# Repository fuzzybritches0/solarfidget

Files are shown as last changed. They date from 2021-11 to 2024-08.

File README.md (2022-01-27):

# 		ORIGINAL SOLARFIDGET LIPO EDITION

Using an LED strip (of 32 WS2812B individually addressable LEDs) and an
MPU6050 gyro/accel, this fidget calculates the position of a rotating
pendulum that reacts to acceleration and gravity and simulates the effect
of gravity on different bodies in our solar system (including Pluto).

Concept, Design and Idea **Copyright (C)** 2021, 2022 Kurt Manucredo, under
the CREATIVE COMMONS ATTRIBUTION-NONCOMMERCIAL 4.0 INTERNATIONAL PUBLIC
LICENSE

For more information on Copyright please refer to the respective files and
LICENSE files.

solarfidget
* * *

There is also a version that runs with 3x AAA batteries. Click on the link
below to follow the instructions for the:

**ORIGINAL SOLARFIDGET - NO BATTERIES INCLUDED EDITION**
<https://github.com/fuzzybritches0/solarfidget/blob/main/README-aaa.md>
* * *

# 1. MANUAL INSTRUCTIONS

## 1.1 TRAVEL FROM PLANET TO PLANET

You can travel the following bodies in our solarsystem in order:

- Mercury (0.38g)   (white)
- Venus   (0.904g)  (light blue)
- Earth   (1g)      (dark blue)
- Mars    (0.3794g) (red brown)
- Jupiter (2.528g)  (white grey)
- Saturn  (1.065g)  (yellow)
- Uranus  (0.886g)  (violet)
- Neptune (1.14g)   (green)
- Pluto   (0.063g)  (pink)

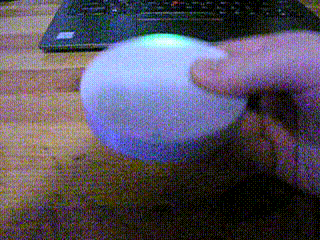
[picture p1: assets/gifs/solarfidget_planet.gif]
solarfidget planet
\
*To travel from planet to planet hold the fidget horizontally, turn it
twice by 180 degrees. If there is no change, try doing it faster.*
* * *

## 1.2 TURN THE LIGHT ON AND OFF

solarfidget off\
*To turn the fidget on or off hold the fidget horizontally, turn it
thrice by 180 degrees. If there is no change, try doing it faster.*

* * *

# 2. HOW TO BUILD ONE FOR YOURSELF

## 2.1 PARTS NEEDED

- 1x Arduino Nano or compatible
- 1x MPU6050 breakout board
- 1x TP4056 battery charging breakout board
- 1x strip of 32 WS2812B individually addressable LEDs (\*)
- 1x 44x24.5x9mm 750mAh LiPo battery with Molex plug
- 1x male Molex plug (\*\*)
- 1x 3d-printed models of both the fidget and charger parts (\*\*\*)
- 1x USB mini cable
- 4x 0.3x4x5 mm compressing spring
- 4x M3 locknut
- 4x M3 nut
- 4x M3x10mm bolt
- 4x M3x4mm bolt
- 8x cylinder magnet d=5mm,h=2mm,
- and a punch of cables one can salvage from old LAN cables or similar.

> (\*):     Use a strip with an LED density of **144 LEDs per metre**.\
> (\*\*):   When buying a set of batteries there is normally a charger
>           included from which you can salvage male Molex plugs.\
> (\*\*\*): all four parts can be found as .3mf files in the
>           design-solarfidget/3mf folder and can be imported directly
>           into the 3d slicer software. If you need to make changes to
>           accommodate your own hardware, use the solarfidget.scad file
>           to do so.

## 2.2 OPENSCAD RENDERINGS

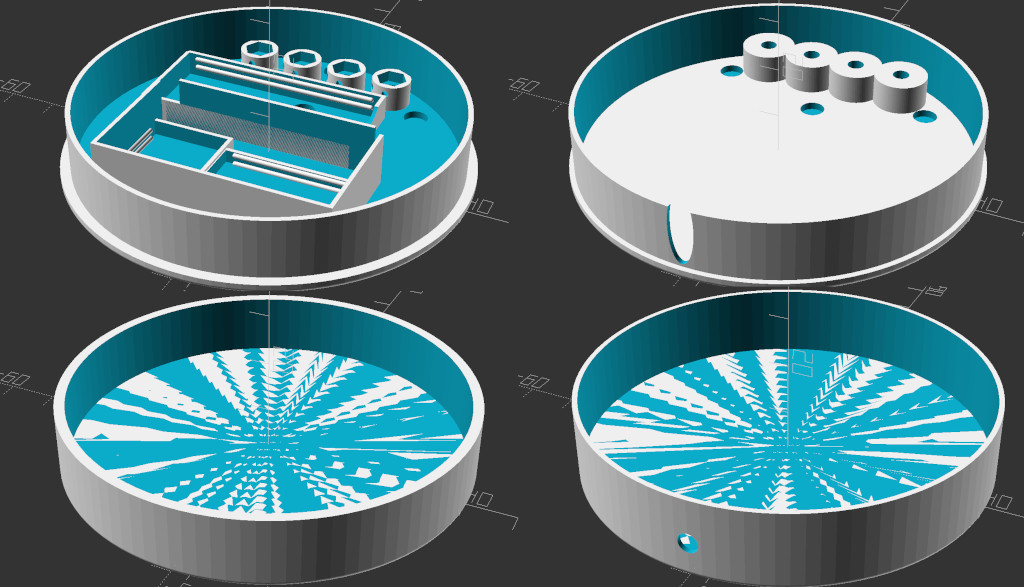
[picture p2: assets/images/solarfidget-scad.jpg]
solarfidget
\
*Pic. 1: The four parts pictured above compose the solarfidget and the
charger*
* * *

## 2.3 PRINTING THE PARTS

I printed the parts with a **PRUSA i3 MKR3s** printer, used the
**PrusaSlicer 2.4.0 software**, selected **0.20mm QUALITY** print settings
with **30% infill** and used a **transparent PLA material**. I printed the
four parts all in one go. It took about 6 hours.

I recommend transparent PLA material. White PLA works, too. The light,
however, will not be as bright. Any other colour will only let through
**that** colour and make it impossible to distinguish between planets.

Using another material than PLA will likely result in slightly different
dimensions and the electronics being loose or too tight to fit. The fit for
the **MPU6050** is particularity crucial and should be very tight to hold
it in place perfectly.

### 2.3.1 Customizing the parts

If you need to make changes to the parts, use the solarfidget.scad file to
do so. At the beginning of the file, change the dimensions of the
electronic parts, then further down, in the file, adjust the placements for
those parts so that they don't overlap. The electronic parts positions can
be altered in the module named ***top***. ***batteryC*** is the **battery
charging breakout board**. If you intend to change the amount of LEDs,
remember, you can only change the amount by a **multiple of 4**.

## 2.4 BUILD INSTRUCTIONS

### 2.4.1 Magnets

Place four magnets inside the charger and four inside the fidget so that
they both lock in place. The magnets go around the charging towers into the
four round holes. Have the magnet's poles in the fidget all oriented in the
same direction. Reverse the poles in the charger. There is no room for
error, since you will have to destroy the parts to remove the magnets. If
you have to do that, turn the parts around and hit the parts with something
pointy and hard (a screw driver will do) at the points where the magnets
are. They will fall out and collect together with each other.

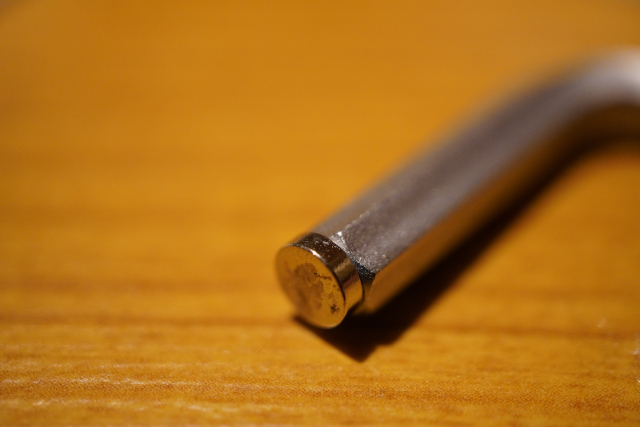
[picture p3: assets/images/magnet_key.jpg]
\
*Pic. 2: Use a crooked M6 key, place the magnet on the crooked end and use a hammer
to fix the magnets in place.*
* * *

### 2.4.2 USB mini cable

Cut the USB mini cable about 10cm from the mini USB plug side. Carefully
remove the PVC coat and the shielding. There should be four cables: one
**black**, one **red**, one **white** and one **green**. Also remove as
much of the hard plastic from the mini USB plug as possible - we only have
limited space - but don't break the plug. We won't be using the **red** or
the **black** cable. If you messed them up, we are still good to go.

### 2.4.3 Fidget

Now, we will work on the part of the fidget that houses all the
electronics, that is, the top part.

Place the top part of the fidget in front of you, facing the inside and
having the charging towers face up. Connect the two cables of the mini USB
plug as follows from left to right (leave the first and fourth empty):
**white**, **green**

Add a red cable for **+5V** to the first tower and a black cable to the
last tower for **GND**. Don't use the cables form the USB plug.

Use the **M3 nuts** and **M3x4mm bolts** to secure the cables. Clean the
inside of the towers if there is loose or deformed material inside from
printing the overhang. Push the nuts inside the towers. This should be
quite easy. If not, use a longer M3 bolt to drive them into place.

Make sure there is **only blank wire** between the nut and the tower. Keep
the blank wire away form the bold. We don't want the wire to curl around
the bolt.

Before we can install the **battery charging breakout board**, we need to
get rid of the USB plug:

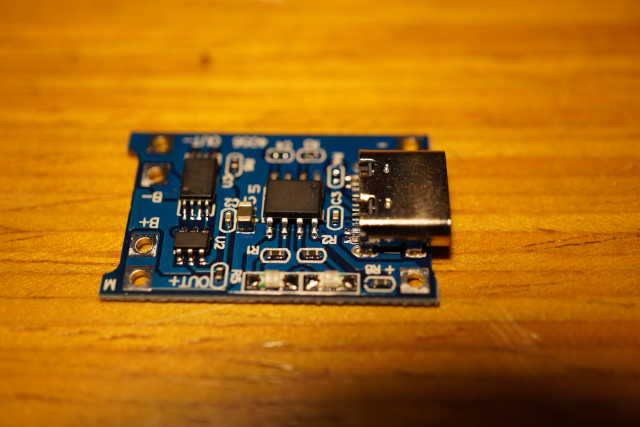
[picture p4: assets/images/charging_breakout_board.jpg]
charging breakout board
\
*Pic. 3:* **Charging breakout board** *with the USB plug.*
* * *

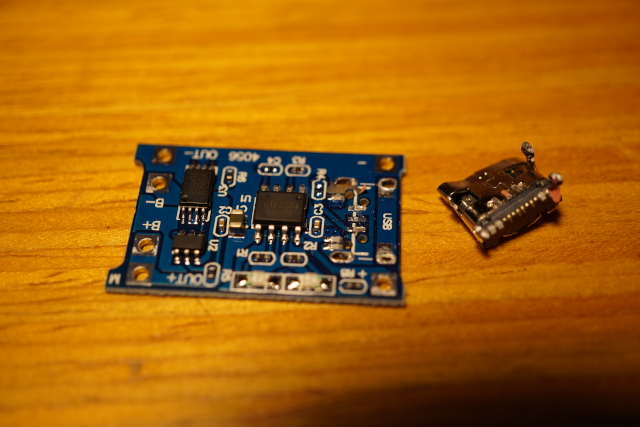
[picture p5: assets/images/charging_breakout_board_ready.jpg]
charging breakout board ready
\
*Pic. 4:* **Charging breakout board** *with the USB plug removed.*
* * *

Connect the **Arduino Nano** to the mini USB plug. Push the **Arduino**
inside its proper place. This shouldn't be too difficult. Push the
**battery charging breakout board** into its proper place. Finally push the
**MPU6050 breakout board** into its proper place. You might have
difficulties there. But try! Eventually, it will go in. It is a very tight
fit. Have the **MPU6050** **face up**. On the **MPU6050** have the
**X-axis** point to the **right and left**.

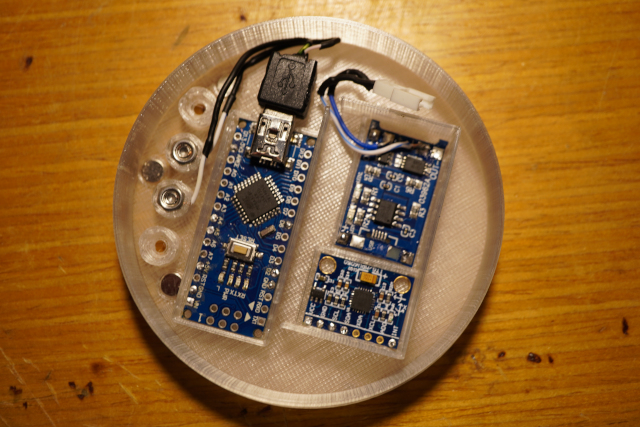
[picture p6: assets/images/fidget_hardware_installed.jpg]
fidget hardware installed
\
*Pic. 5: Magnets and hardware installed.* **Arduino** *plugged in.*
* * *

### 2.4.4 LED strip

Solder three spots onto the **32 addressable LED strip**. Note the
direction of the arrows on the strip and solder the spots on the right end.
If the arrow points to the end of the strip, it's the wrong end.

led strip solder spots\
*Pic. 6: Solder the spots onto the back.*
* * *

Place the strip around the inside of the fidget's top part. Start with the
centre of the first LED at **9 o'clock** and continue **clockwise**.

### 2.4.5 Soldering

Wire all cables left and right through the openings in the battery
compartment, if they come from the **MPU6050** or **battery charging
breakout board**. Keep the cables as short as possible. Have them stacked
on both sides of the **battery**, left and right, so that the **battery**
gets a nice fit. They should not stack below the **battery**. If so, you
won't be able to close up the fidget, or even damage the **battery** or
other components, when you try. Have them go next to each other. 

#### 2.4.5.1 Battery charging breakout board

All spots marked with the **Minus (-)**, on the **battery charging breakout
board**, are the same. **Ground** that board to the **Arduino**. Solder the
**red** cable from the charging tower to **+In** on the **battery charging
breakout board**. Use the **black** cable to ground the board.

Solder **OUT+** from the **battery charging breakout board** to **VIN** on
the **Arduino**. 

#### 2.4.5.2 MPU6050

Solder **VIN** from the **MPU6050** to **3V3** on the **Arduino** and
**ground** the **MPU6050** on the **battery charging breakout board**.
Now, solder **SCL**, **SDA** and **INT** from the **MPU6050** to **A5**,
**A4** and **D2** on the **Arduino**, respectively.

#### 2.4.5.3 MOLEX plug

Solder two cables to the **male MOLEX plug**. When you connect a battery to
the plug, you can see which cable is which. Make sure the plug and cable
are properly isolated. Use **shrink tubing**. ***Never solder with a
connected battery!*** Don't bend the cables around the solder spots at the
**MOLEX plug**. This will lead to broken contacts.

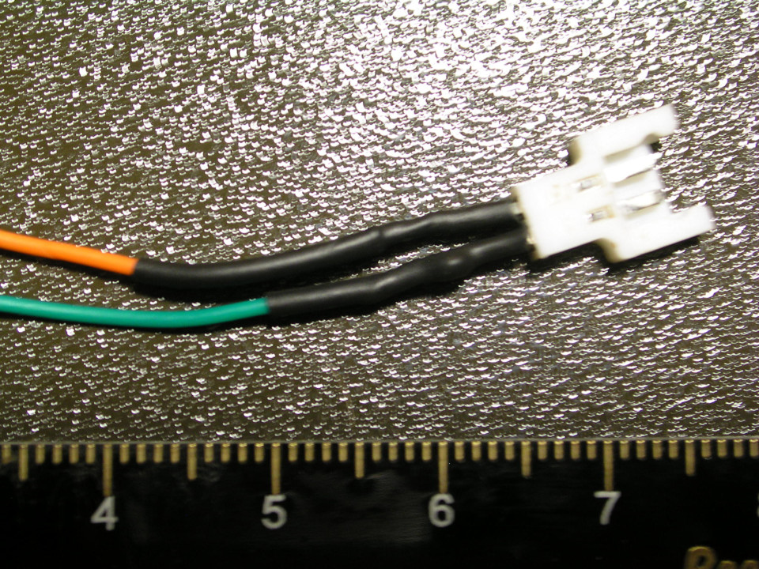
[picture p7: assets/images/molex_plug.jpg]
molex_plug
\
*Pic. 7:* **Male Molex plug**.
* * *

Solder the two cables to **BAT+** and **BAT-** on the **battery charging
breakout board**, accordingly. **If you do it the wrong way and connect a
battery, your board will get fried and smoke will come out.**

#### 2.4.5.4 LED strip

Now, solder a **red** cable to **+5V**, a **black** cable to **GND**
(either on the **Arduino** or the **battery charging breakout board** -
whichever is easier for you) and a different coloured cable to **D6** on
the **Arduino**. Then solder them to **Plus (+)**, **DATA** and **Minus
(-)** on the **LED strip**, respectively; that is, the top most solder spot
is **Plus (+)**, the middle one is **DATA** and the lowest one is **Minus
(-)**.

#### 2.4.5.5 Battery

Now, connect the **battery** to the **MOLEX plug** and place it inside the
fidget.

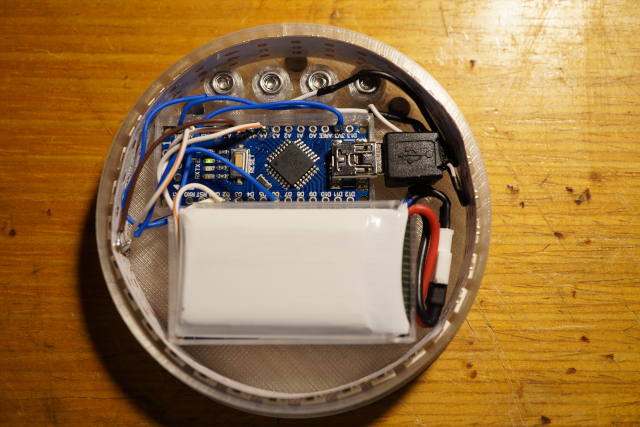
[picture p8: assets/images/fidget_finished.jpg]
fidget finished
\
*Pic. 8: This is about what it should look now.*
* * *

### 2.4.6 Charging station

**Don't forget** to route the cable through the bottom part of the charging
station first, before you continue. Clean the inside of the towers if
needed.

Use the **0.3x4x5 mm compressing springs**, the **M3 locknuts** and the
**M3x10mm bolts** to finish up the charger. Have the bolts look out of the
charger around **one mm**, enough so that the fidget gets good contact when
pushed down by the magnets. Get it right now. Later on, it will be very
difficult to change.

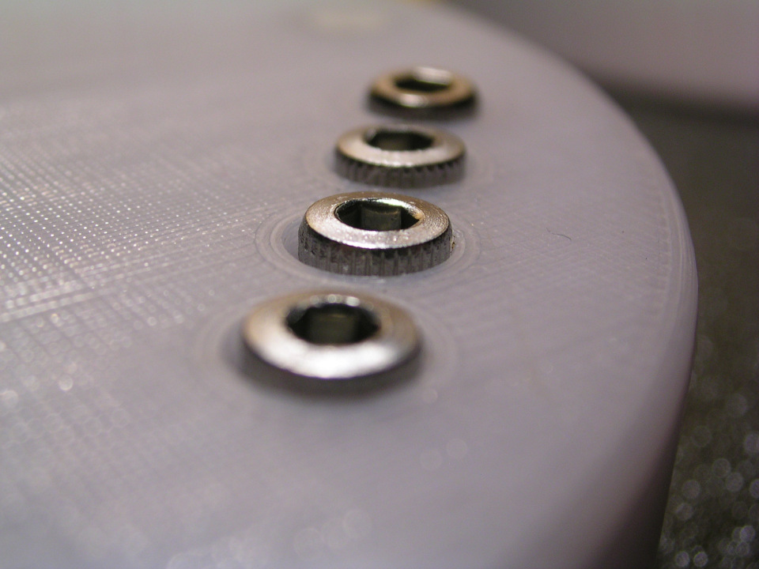
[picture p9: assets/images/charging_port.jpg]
charging port
\
*Pic. 9: Here you see the bolts looking out a little.*
* * *

To figure out which cable goes where place the fidget's charging towers
next to the charging station's charging towers.

Now, wind the blank wires of the four cables around the end of the bolts.
Have as much blank wire as possible go around and make it really tight.

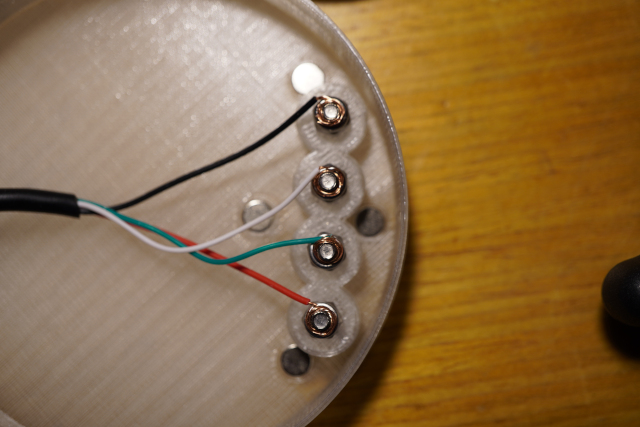
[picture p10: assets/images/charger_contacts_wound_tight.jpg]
charger contacts wound tight
\
*Pic. 10: The wire is wound up around the bolts tight, so as to give a good
contact and reduce the resistance as much as possible.*
* * *

Now, apply tin-solder on all of the blank wire.

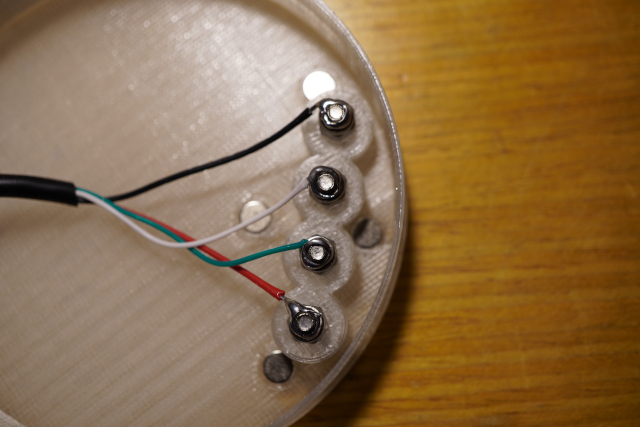
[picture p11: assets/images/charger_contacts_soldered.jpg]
charger contacts soldered
\
*Pic. 11: The wire will act as a sponge when you apply tin-solder. Apply
plenty.*

Before we close up the fidget we need to do the software and fine-tune the
position of the **LED strip**.

### 2.4.7 Software

Copy or link the folder in `arduino-solarfidget/libraries/solarfidget` into
your `Arduino/libraries` folder.

Place the files at:
<https://github.com/jrowberg/i2cdevlib/tree/master/Arduino/I2Cdev>
in a subdirectory in your `Arduino/libraries` folder

Place the files at:
<https://github.com/jrowberg/i2cdevlib/tree/master/Arduino/MPU6050>
in a subdirectory in your `Arduino/libraries` folder

Place the files at:
<https://github.com/adafruit/Adafruit_NeoPixel>
in a subdirectory in your `Arduino/libraries` folder

Open the **Arduino IDE** and load the file:
`arduino-solarfidget/arduino-solarfidget.ino`

Place the fidget on top of the charger, the charger on a level surface and
connect it to your computer. Open the serial monitor. Compile and upload
the programme to the **Arduino**. Wait for the **Arduino** to reset and
start. Look at the serial monitor and note down the **calibration values**.

Now, in the file:
`arduino-solarfidget/arduino-solarfidget.ino` find the following line:

```
#define SERIAL_DEBUG
```

Comment out this line so that it looks like this:

```
//#define SERIAL_DEBUG
```

Find and uncomment the line:

```
//#define FIDGET 1
```

Now, find the lines:

```
#if (FIDGET == 1)
    // Fill in your calibration values here
    mpu.setXAccelOffset(0);
    mpu.setYAccelOffset(0);
    mpu.setZAccelOffset(0);
    mpu.setXGyroOffset(0);
    mpu.setYGyroOffset(0);
    mpu.setZGyroOffset(0);
#endif
```

and replace the **0 values** with the values you just noted down for Gyro
and Accel.

Save the file and upload the programme again.

Finally make sure the **LED strip** is placed correctly in the fidget and the
light of the pendulum is at the right spot. Do this by holding the fidget
askew and wait for the pendulum to rest. Now, move the strip either left
or right to bring the light into the correct position.

After that, slide the other part of the fidget on.

If you want power saving, uncomment the following line.

```
//#define POWERSAVING
```

If in power saving mode, before you try enabling the fidget, hold it for a
few seconds in your hands. If you have trouble enabling it, just flip it
continuously by 180 degrees until it enables.

Power saving mode is only active when the fidget is off and sitting still.

You should all be set now. Have fun travelling our solar system.

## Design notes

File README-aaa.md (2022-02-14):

# 	ORIGINAL SOLARFIDGET - NO BATTERIES INCLUDED EDITION

Using an LED strip (of 32 WS2812B individually addressable LEDs) and an
MPU6050 gyro/accel, this fidget calculates the position of a rotating
pendulum that reacts to acceleration and gravity and simulates the effect
of gravity on different bodies in our solar system (including Pluto).

Concept, Design and Idea **Copyright (C)** 2021, 2022 Kurt Manucredo, under
the CREATIVE COMMONS ATTRIBUTION-NONCOMMERCIAL 4.0 INTERNATIONAL PUBLIC
LICENSE

For more information on Copyright please refer to the respective files and
LICENSE files.

solarfidget
* * *

# 1. MANUAL INSTRUCTIONS

## 1.1 TRAVEL FROM PLANET TO PLANET

You can travel the following bodies in our solarsystem in order:

- Mercury (0.38g)   (white)
- Venus   (0.904g)  (light blue)
- Earth   (1g)      (dark blue)
- Mars    (0.3794g) (red brown)
- Jupiter (2.528g)  (white grey)
- Saturn  (1.065g)  (yellow)
- Uranus  (0.886g)  (violet)
- Neptune (1.14g)   (green)
- Pluto   (0.063g)  (pink)

solarfidget planet\
*To travel from planet to planet hold the fidget horizontally, turn it
twice by 180 degrees. If there is no change, try doing it faster.*
* * *

## 1.2 TURN THE LIGHT ON AND OFF

To turn the fidget on, turn the upper half clockwise. To turn it off, turn
the upper half counter-clockwise.

* * *

# 2. HOW TO BUILD ONE FOR YOURSELF

## 2.1 PARTS NEEDED

- 1x Arduino Nano or compatible
- 1x MPU6050 breakout board
- 1x 5 Volts Voltage-Step-Up-Booster 0.9-5 Volts
- 1x strip of 32 WS2812B individually addressable LEDs (\*)
- 1x 4-pin 6x6x5 push button, 0.4mm push distance
- 1x 3d-printed models of the fidget (\*\*\)
- 3x 0.6x6.5x10 mm compressing spring
- 3x M3 DIN 9021 washer
- single wire 0.5mm diameter
- and a punch of cables one can salvage from old LAN cables or similar.

> (\*):   Use a strip with an LED density of **144 LEDs per metre**.\
> (\*\*): all two parts can be found as .3mf files in the
> design-solarfidget/3mf folder and can be imported directly into the 3d
> slicer software. If you need to make changes to accommodate your own
> hardware, use the solarfidget-aaa.scad file to do so.

## 2.2 OPENSCAD RENDERINGS

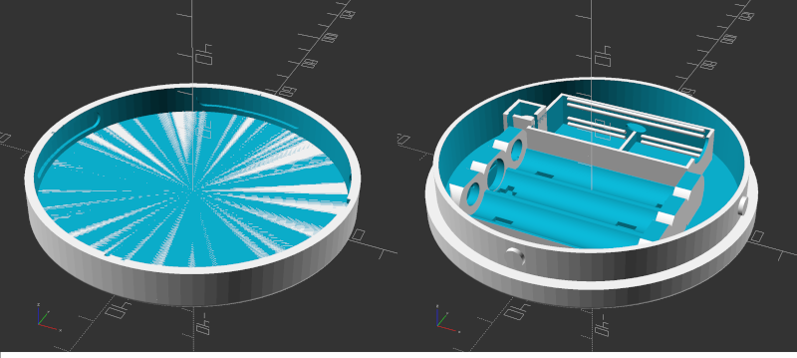
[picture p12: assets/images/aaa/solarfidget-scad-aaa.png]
solarfidget
\
*Pic. 1: The two parts pictured above compose the solarfidget*
* * *

## 2.3 PRINTING THE PARTS

After printing the parts, let them cool down all the way.

Next, carefully try to close the two parts and turn one part left and right
slowly. If you notice too much resistance open them again and use sanding
paper to sand down the locking towers. Always sand them down just a little
and then try again. If you sand them down too much the whole mechanism may
get too loose. If you sand them down too little it might get impossible to
unlock and open them again.

I've set the towers so that practically no sanding is required. Only some
force is required to repeatedly close, lock, unlock and open them again,
until the process works without much force. But every material is
different. Even one PLA material may differ from another PLA material.

I printed the parts with a **PRUSA i3 MKR3s** printer, used the
**PrusaSlicer 2.4.0 software**, selected **0.20mm QUALITY** print settings
with **30% infill** and used a **transparent PLA material**. I printed the
two parts all in one go. It took about 4 hours.

I recommend transparent PLA material. White PLA works, too. The light,
however, will not be as bright. Any other colour will only let through
**that** colour and make it impossible to distinguish between planets.

Using another material than PLA will likely result in slightly different
dimensions and the electronics being loose or too tight to fit. The fit for
the MPU6050 is particularity crucial and should be very tight to hold it in
place perfectly.

### 2.3.1 Customizing the parts

If you need to make changes to the parts, use the solarfidget-aaa.scad file
to do so. At the beginning of the file, change the dimensions of the
electronic parts, then further down, in the file, adjust the placements for
those parts so that they don't overlap. The electronic parts positions can
be altered in the module named ***electronics***. If you intend to change
the amount of LEDs, remember, you can only change the amount by a
**multiple of 4**.

## 2.4 BUILD INSTRUCTIONS

### 2.4.1 Prepare the Voltage Step Up Module

First, remove the USB plug from the module.

Next, we need to shorten the module a bit.

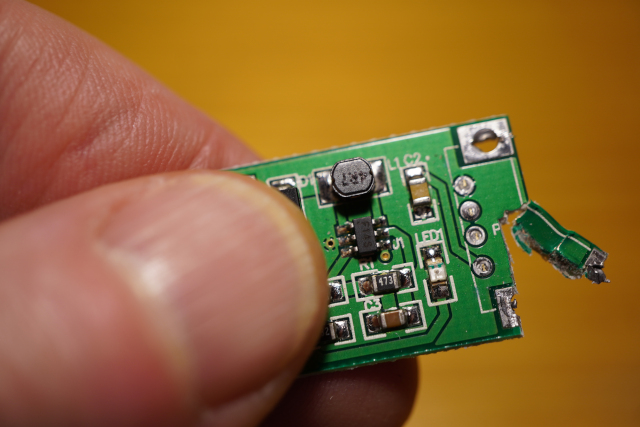
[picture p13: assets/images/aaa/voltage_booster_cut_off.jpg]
voltage booster cut off
\
*Pic. 2: Cut away as much as possible. But don't cut off the USB solder
spots.*
* * *

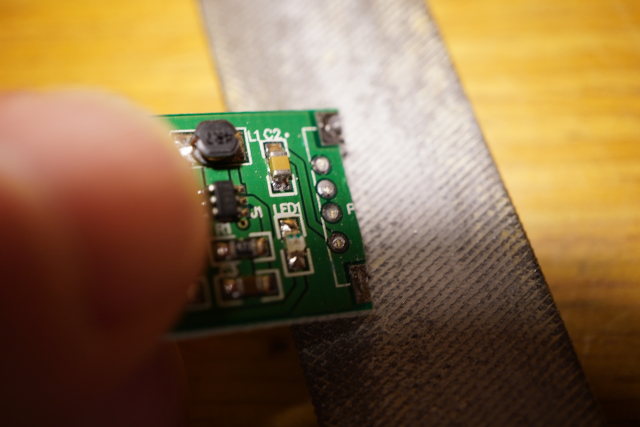
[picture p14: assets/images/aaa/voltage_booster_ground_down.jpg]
voltage booster ground down
\
*Pic. 3: Grind down until short enough.*
* * *

Then remove the remaining tin-solder and remains of the USB plug.

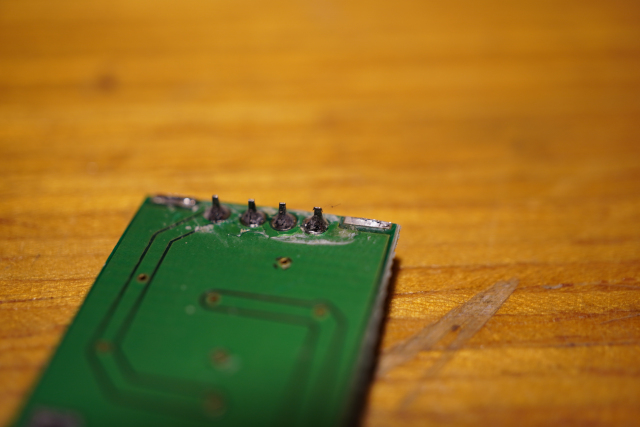
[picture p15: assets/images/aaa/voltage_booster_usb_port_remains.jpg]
voltage booster usb port remains
\
*Pic. 4: We need to get rid of those four dips on the underside of the
module.*
* * *

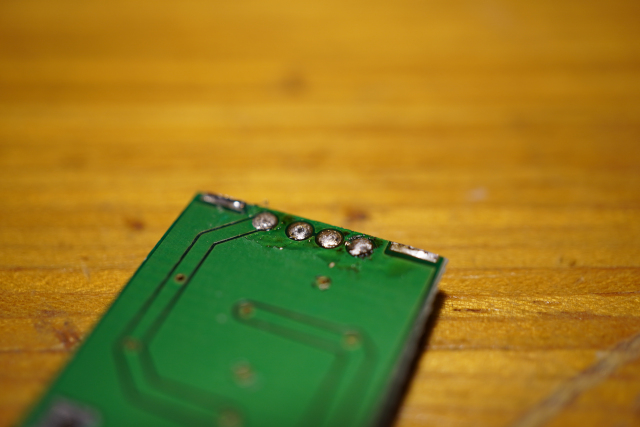
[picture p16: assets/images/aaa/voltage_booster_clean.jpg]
voltage booster clean
\
*Pic. 5: That's what we want! All clean now.*
* * *

### 2.4.2 AAA battery compartment

Cut two pieces of **0.5 diameter blank wire** to the right length and
insert them, one on each side of the batteries compartment. One between the
**Plus (+)** and **Minus (-)**, the other between the **Minus (-)** and
**Plus (+)**.

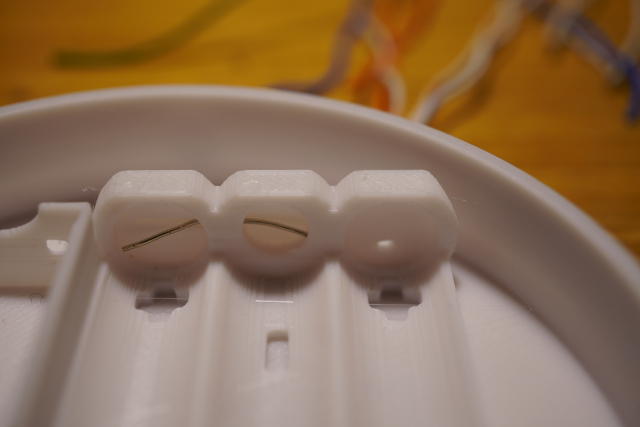
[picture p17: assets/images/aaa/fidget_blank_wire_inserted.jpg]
fidget blank wire inserted
\
*Pic. 6: The wire connects the two poles and connects the batteries
serially*
* * *

Next, insert two washers into the two **Plus (+)** poles. Use a M6 key or
something with which you can apply force to get it in. I never managed to
break the plastic. But if you want to make sure, use your thumb to push
against the other side. **Don't** push a third washer into the last
**Plus (+)** pole. We'll do this later.

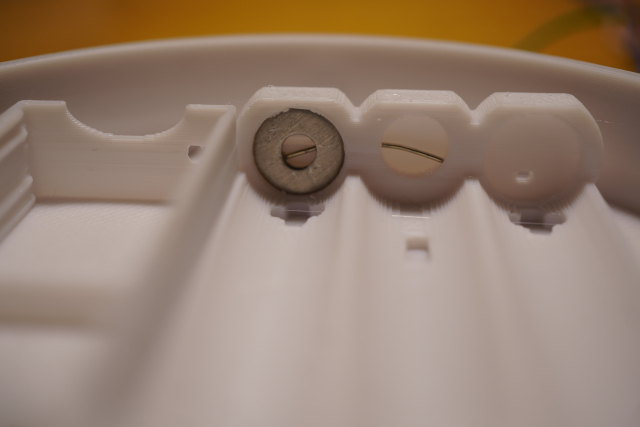
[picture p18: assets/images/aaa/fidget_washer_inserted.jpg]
fidget blank wire inserted
\
*Pic. 7: The washers need to sit tight and deep enough to get in contact
with the blank wire.*
* * *

Next, insert two compressing springs into the **Minus (-)** poles. This
might be a bit tricky. Again, **don't** insert the third spring, we'll do
this later.

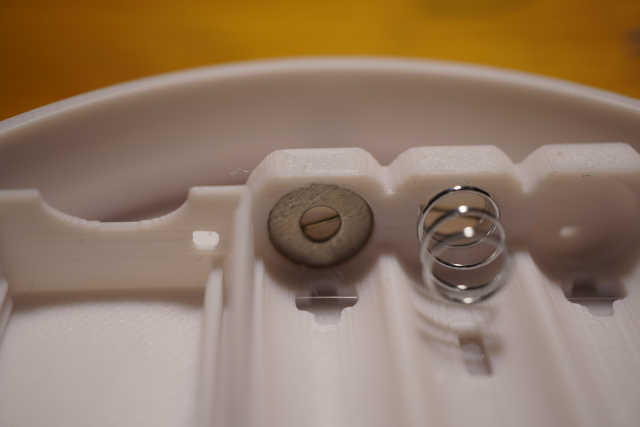
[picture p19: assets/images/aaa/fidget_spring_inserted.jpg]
fidget blank wire inserted
\
*Pic. 8: The springs need to sit tight and deep enough to get in contact
with the blank wire.*
* * *

### 2.4.3 Install the Voltage Booster Module

Before we can continue with the rest, we put the **Voltage Booster Module**
in its right place.

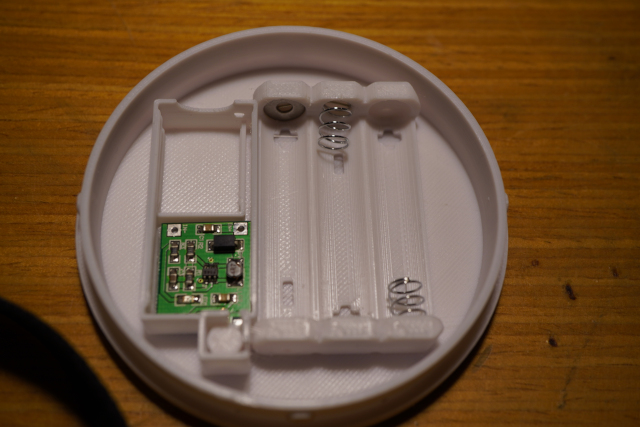
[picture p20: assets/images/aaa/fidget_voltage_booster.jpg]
fidget voltage booster
\
*Pic. 9: That looks nice!*
* * *

### 2.4.4 Install Push Button

Use a short **0.5 diameter single wire** and strip it on both sides. One
shorter, the other longer. Now, place the longer blank wire into the last
**Minus (-)** pole and push the last spring in there.

Now, take the push button and solder that wire with the shorter blank end
onto one of the terminals, so the circuit will only close if the button is
pushed. Use another wire, solder it to the other terminal and then onto the
**-In** of the **Voltage Booster Module**. Then push the button into its
proper place and make sure its level with the quadratic plastic end.

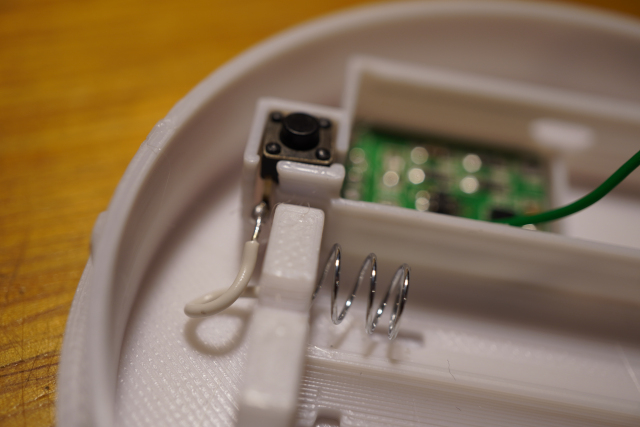
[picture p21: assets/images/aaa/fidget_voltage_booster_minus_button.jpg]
fidget voltage booster minus button
\
*Pic. 10: There, last spring installed and wire soldered on. Solder it on
before you push the button in it's place.*
* * *

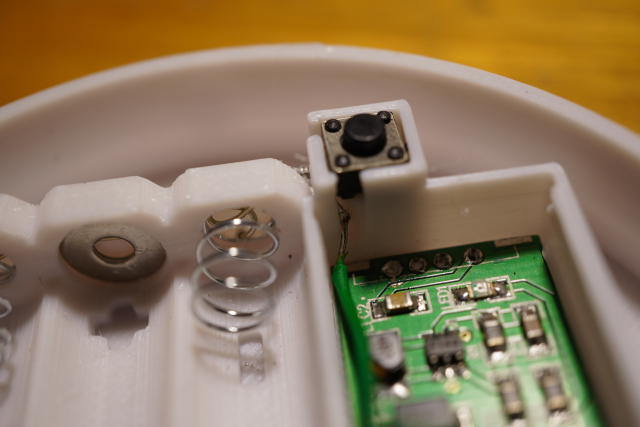
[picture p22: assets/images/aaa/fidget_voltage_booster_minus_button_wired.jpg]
fidget voltage booster minus button wired
\
*Pic. 11: This is the other side. The green cable goes to the* **-In** *of
the* **Voltage Booster Module**.
* * *

Next, we use another wire, strip it again on both sides, one shorter,
one longer and insert it into the last **Plus (+)** pole.

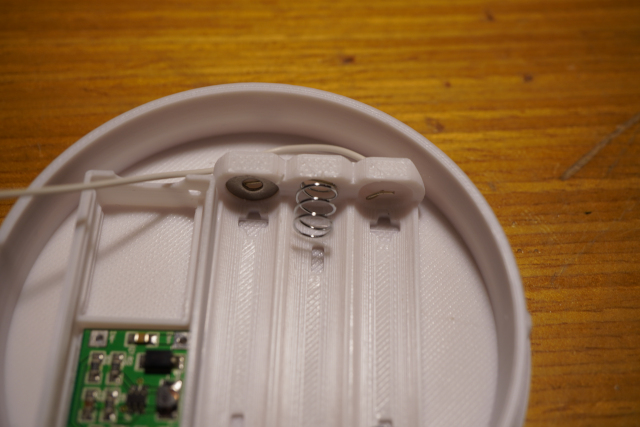
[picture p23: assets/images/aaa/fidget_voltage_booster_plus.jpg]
fidget voltage booster plus
\
*Pic. 12: There! Way to go!*
* * *

Then route it through the little hole next to the place where the
**MPU6050** will go. There is place next to the **MPU6050**, so don't route
it over the **MPU6050**. Push the last washer in and solder the wire to the
**Voltage Booster Board** on its **In+** pole.

If this is all done, insert three batteries and test the mechanism. Close
the two parts and try out. If you see the **Voltage Booster Module** light
up, congratulations, you've done it.

If not, the fault may be with the button or the contacts of the batteries
compartment. Push the washers and springs harder in. Then check the button
by pressing it without closing the two parts. Check again with the two
parts closed. If it doesn't work, the button may be too deep inside. Put a
thin plastic or something hard and thin between the button tower and the
button and try to fix it that way.

If it works no matter which way you turn the upper part, when closed, then
the button is too high. Try to grind down the button tower to fix it.
Although, this might be a difficult task. I recommend altering the button
tower in the solarfidget-aaa.scad design file.

If the **Voltage Booster Module** enables as soon as you install all
batteries you soldered the wires to the wrong terminals on the button.

### 2.4.5 Soldering

Keep all wires as short as possible. We will solder the wires first onto
the **MPU6050** and **Voltage Booster Module** then stick them from below
into the **Arduino** and solder them on from above the **Arduino**. If the
wires are too long, we won't be able to push the **Arduino** into its
place.

#### 2.4.5.1 Voltage Booster Module

Solder a **red cable** onto the **Voltage Booster Module** where the boosted
voltage will come out.

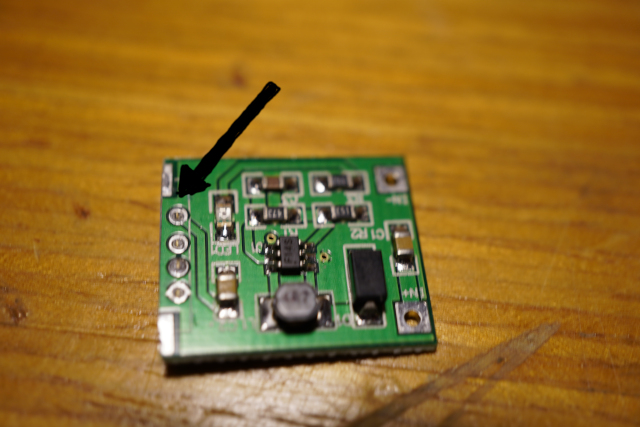
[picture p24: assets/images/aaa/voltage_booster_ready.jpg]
voltage booster ready
\
*Pic. 13: There! It's that round spot where the trace leads away to the
resistor.*
* * *

Next, solder two **black cables** to **In-**. Solder one of them to **GND**
on the **MPU6050**. Leave the other for the **Arduino**.

#### 2.4.5.2 MPU6050

Now, solder four cables onto the **MPU6050**, one onto **VIN**, one onto
**SCL**, one onto **SDA** and another onto **INT**. Keep them short.

#### 2.4.5.3 Arduino

Have the **red cable** stick through **VIN** and the **black cable** stick
through **GND** on the **Arduino**. Have the cables coming from **SCL**,
**SDA** and **INT** stick through **A5**, **A4** and **D2**, respectively.

Now solder them on from above.

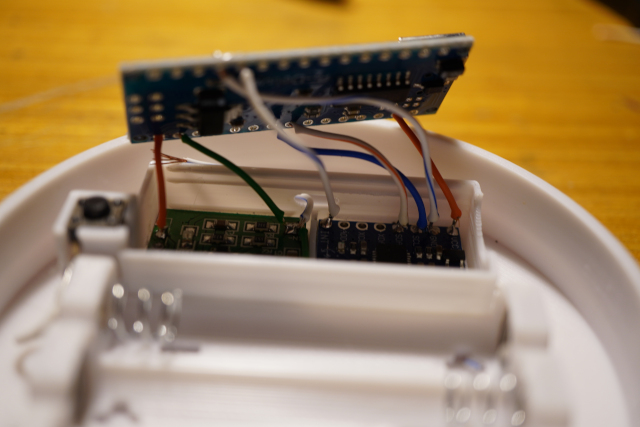
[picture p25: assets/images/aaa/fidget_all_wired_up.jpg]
fidget all wired up
\
*Pic. 14: That looks about right. Maybe you can get those cables a bit
shorter. It's a tight fit here, but it works. Fold them in carefully.*
* * *

#### 2.4.5.4 32 addressable LED strip

Next, find that elliptical hole between the **Arduino** and the **MPU6050**.
We'll use it to route the cables for the **LED strip** through it. But first,
we'll prepare the **LED strip**.

Solder three spots onto the **32 addressable LED strip**. Note the
direction of the arrows on the strip and solder the spots on the right end.
If the arrow points to the end of the strip, it's the wrong end.

led strip solder spots\
*Pic. 15: Solder the spots onto the back.*
* * *

Place the **LED strip** around the inside of the fidget's top part. Start with
the centre of the first LED at **9 o'clock** and continue **clockwise**. **9
o'clock** is where the elliptical hole is located.

Now, solder a **red** cable to **+5V**, a **black** cable to **GND** and a
different coloured cable to **D6** on the **Arduino**. Now, route them through
that elliptical hole. Then solder them to **Plus (+)**, **DATA** and **Minus
(-)** on the LED strip, respectively; that is, the top most solder spot is
**Plus (+)**, the middle one is **DATA** and the lowest one is **Minus (-)**.

### 2.4.6 Software

Copy or link the folder in `arduino-solarfidget/libraries/solarfidget` into
your `Arduino/libraries` folder.

Place the files at:
<https://github.com/jrowberg/i2cdevlib/tree/master/Arduino/I2Cdev>
in a subdirectory in your `Arduino/libraries` folder

Place the files at:
<https://github.com/jrowberg/i2cdevlib/tree/master/Arduino/MPU6050>
in a subdirectory in your `Arduino/libraries` folder

Place the files at:
<https://github.com/adafruit/Adafruit_NeoPixel>
in a subdirectory in your `Arduino/libraries` folder

Open the **Arduino IDE** and load the file:
`arduino-solarfidget/arduino-solarfidget.ino`

Place the fidget on a level surface and connect it to your computer. Open
the serial monitor. Compile and upload the programme to the **Arduino**.
Wait for the **Arduino** to reset and start. Look at the serial monitor and
note down the **calibration values**.

Now, in the file:
`arduino-solarfidget/arduino-solarfidget.ino` find the following line:

```
#define SERIAL_DEBUG
```

Comment out this line so that it looks like this:

```
//#define SERIAL_DEBUG
```

Find and uncomment the line:

```
//#define FIDGET 1
```

Now, find the lines:

```
#if (FIDGET == 1)
    // Fill in your calibration values here
    mpu.setXAccelOffset(0);
    mpu.setYAccelOffset(0);
    mpu.setZAccelOffset(0);
    mpu.setXGyroOffset(0);
    mpu.setYGyroOffset(0);
    mpu.setZGyroOffset(0);
#endif
```

and replace the **0 values** with the values you just noted down for Gyro
and Accel.

Then, comment the following line:

```
#define AUTO_OFF
```

We don't want the fidget to turn off the light. If we don't want to play
with the fidget, we'll turn it off with the on/off mechanism.

Save the file and upload the programme again.

Finally make sure the LED strip is placed correctly in the fidget and the
light of the pendulum is at the right spot. Do this by holding the fidget
askew and wait for the pendulum to rest. Now, move the strip either left
or right to bring the light into the correct position.

After that, push the **Arduino** into its place.

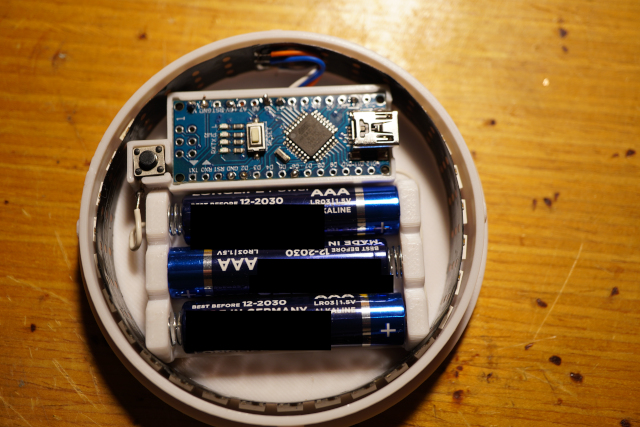
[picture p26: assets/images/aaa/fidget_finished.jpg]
fidget finished
\
*Pic. 16: All done. Batteries inserted.*
* * *

You should all be set now. Have fun travelling our solar system.

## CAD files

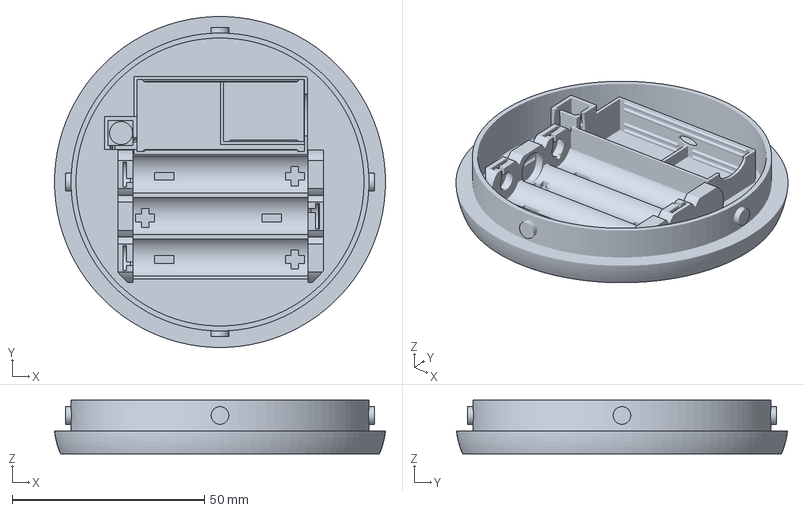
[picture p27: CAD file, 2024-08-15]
design-solarfidget/3mf/solarfidget-aaa-bottom.3mf
86.2 x 86.2 x 14.0 mm

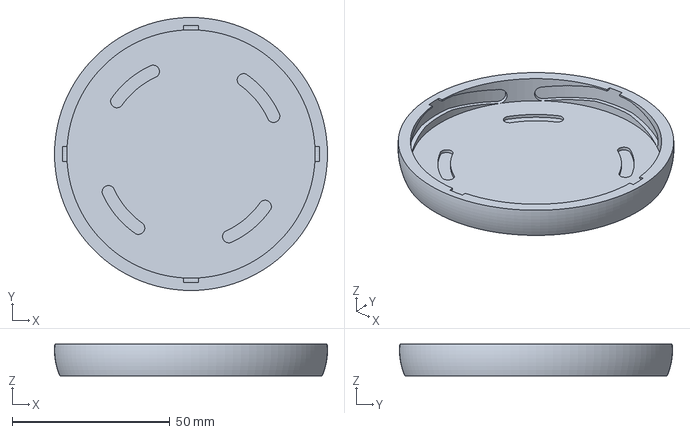
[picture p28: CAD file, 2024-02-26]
design-solarfidget/3mf/solarfidget-aaa-top.3mf
86.4 x 86.4 x 10.0 mm

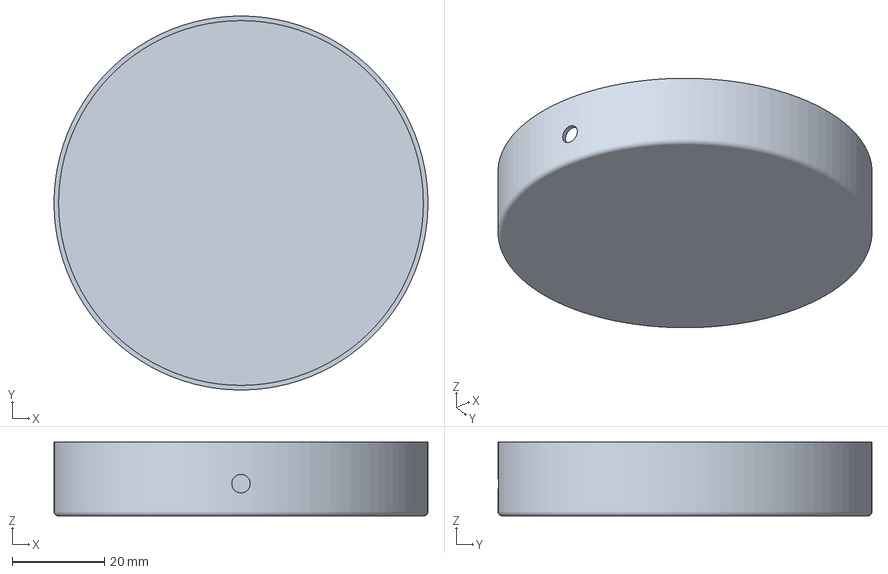
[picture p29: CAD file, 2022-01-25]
design-solarfidget/3mf/solarfidget-charger-bottom.3mf
80.9 x 80.9 x 16.0 mm

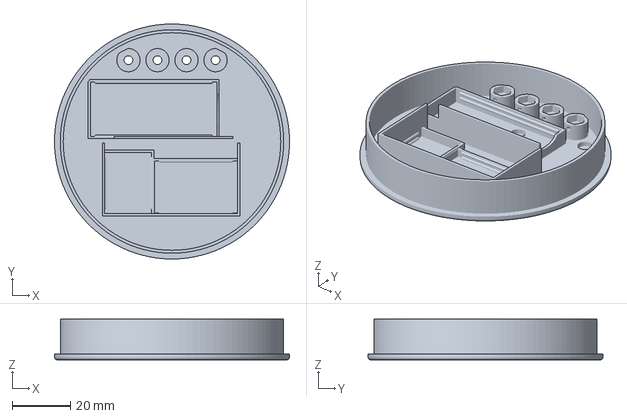
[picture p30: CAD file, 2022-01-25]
design-solarfidget/3mf/solarfidget-top.3mf
80.9 x 80.9 x 14.0 mm

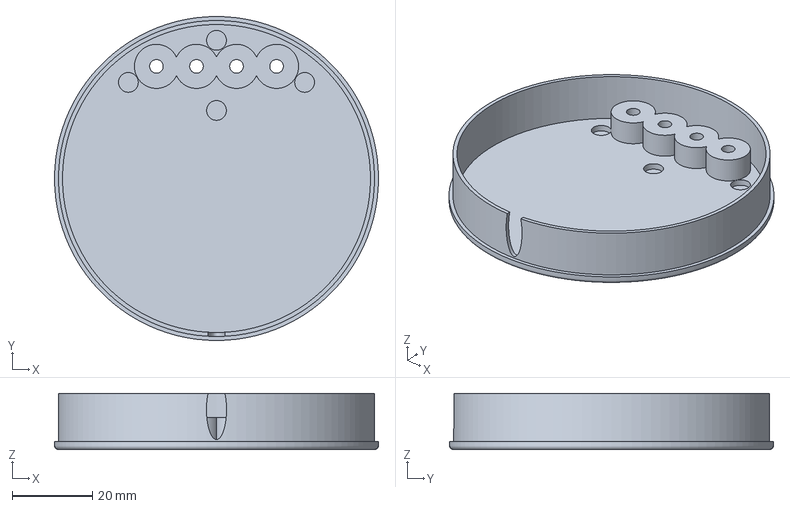
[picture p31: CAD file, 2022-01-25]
design-solarfidget/3mf/solarfidget-charger-top.3mf
80.9 x 80.9 x 14.0 mm

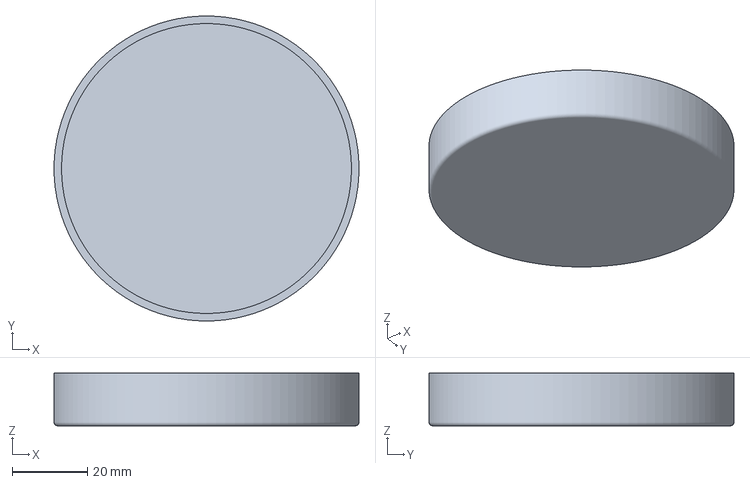
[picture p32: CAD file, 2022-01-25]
design-solarfidget/3mf/solarfidget-bottom.3mf
80.9 x 80.9 x 14.0 mm

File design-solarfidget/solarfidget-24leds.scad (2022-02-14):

//*** DO NOT USE FOR PRINTING - IT WILL NOT WORK ***//
//*** THIS FILE IS HERE FOR DOCUMENTING PURPOSES ONLY ***//


// This was the very first version designed. It uses a 24led ring, where the
// leds look up instead of to the side. I have tried several iterations of a
// charger mechanism but failed every time. I abandoned this design due to the
// space being too limited. Most of the software, however, was written using
// this unfinished design as a development platform.

// (ORIGINAL) SOLARFIDGET Copyright (C) 2021, 2022 Kurt Manucredo

// (ORIGINAL) SOLARFIDGET is licensed under a
// CREATIVE COMMONS ATTRIBUTION-NONCOMMERCIAL 4.0 INTERNATIONAL PUBLIC
// LICENSE

// You should have received a copy of the license along with this
// work.  If not, see:
// <https://creativecommons.org/licenses/by-nc/4.0/legalcode>

arduinoLength=43.45;
arduinoWidth=18.9;
mpuLength=16.1;
mpuWidth=21;
upperLength=17.3;
upperWidth=mpuWidth;
batteryCLength=25.7;
batteryCWidth=19.7;

wall=1.5;
walle = .9;
wallHeight=2.5;
looseFit=.07;

heightBottom=2;
heightLEDS=3;
heightBattery=8.2;
batteryLength=38;
batteryWidth=20;
heightElectronics=7.2;
height=heightBattery+heightElectronics+1;

res=100;

innerRad=33.2 + looseFit;
outerRad=innerRad+wall;

lightsRad=30;
screwShaftRadius=2.4;
screwRadius=1.5;
holeRad=2;
screwOne=[0,23.3,3];
screwTwo=[24,0,3];
screwThree = [0,-23,3];


arduinoX=-23;
arduinoY=-19.5;

mpuX=4;
mpuY=0;
upperX=-mpuLength/2-upperLength-wall;
upperY=-upperWidth/2+1.8;

lowerX=mpuLength/2+wall;
lowerY=-upperWidth/2+1.8;

batteryCX=-22.5;
batteryCY=0;

charging_wire_radius=.7;
ridgesRad=.5;

module batteryCompartment() {
    difference() {
        translate([0,0,0]) rotate([0,0,0]) cube([batteryLength+walle*3, batteryWidth+walle*3, heightBattery/1.3+walle]);
        translate([walle,walle,walle]) rotate([0,0,0]) cube([batteryLength+walle, batteryWidth+walle, heightBattery/1.3+walle]);
        translate([-2,-2,-1]) cube([5,5,10]);    
    }
}

module spacerTowers(hShaft) {
    translate(screwOne) resize([15,0,0]) cylinder(r=1.8,h=hShaft, $fn=res); 
    translate(screwTwo) resize([0,15,0]) cylinder(r=1.8,h=hShaft, $fn=res);
    translate(screwThree) resize([15,0,0]) cylinder(r=1.8,h=hShaft, $fn=res);
}

module holes(count=24) {
    for (i=[1:count]) {
        translate([lightsRad*cos(i*(360/count)), lightsRad*sin(i*(360/count)), 0])
        cylinder(r=holeRad, h=height, $fn=res);
    }
}

module clearCorners(r) {
    translate([0,0,0]) rotate_extrude(convexity = 10, $fn=res)
    translate([r, 0, 0])
    circle(r=1, $fn=res);
}

module roundCorners(r) {
    translate([0,0,1]) rotate_extrude(convexity = 10, $fn=res)
    translate([r-1, 0, 0])
    circle(r=1, $fn=res);
}

module compartmentOutside(location, size) {
    translate([location[0]-walle, location[1]-walle, location[2]-walle]) cube([size[0]+walle*2, size[1]+walle*2, size[2]]);
}
module compartmentInside(location, size) {
    translate([location[0], location[1], location[2]-4]) cube([size[0], size[1], size[2]+5]);
}

module ridge(location,size) {
    translate(location) translate([wall,0,-2]) rotate([0,90,0]) cylinder(r=ridgesRad,h=size[0]-wall*2, $fn=res);
    translate(location) translate([wall,0,-2]) sphere(r=ridgesRad, $fn=res);
    translate(location) translate([wall+size[0]-wall*2,0,-2]) sphere(r=ridgesRad, $fn=res);
}

module ridgesCompartment(location, size) {
    translate([0,0,-1]) ridge(location, size);
    translate([0,0,-3.05]) ridge(location, size);
    translate([0,size[1],-1]) ridge(location, size);
    translate([0,size[1],-3.05]) ridge(location, size);
}

module electronics() {
    arduinoZ=heightElectronics-wallHeight;
    difference() {
        union() {
                translate([-.8,.5,wallHeight+walle/2]) cylinder(r=innerRad - looseFit - walle * 2, h=walle, $fn=res);
            compartmentOutside([arduinoX, arduinoY, arduinoZ], [arduinoLength, arduinoWidth, wallHeight]);
            compartmentOutside([mpuX,mpuY,arduinoZ], [mpuLength,mpuWidth,wallHeight]);
            compartmentOutside([batteryCX,batteryCY,arduinoZ], [batteryCLength,batteryCWidth,wallHeight]);
        }
        compartmentInside([arduinoX, arduinoY, arduinoZ], [arduinoLength, arduinoWidth, wallHeight]);
        compartmentInside([mpuX,mpuY,arduinoZ], [mpuLength,mpuWidth,wallHeight]);
        compartmentInside([batteryCX,batteryCY,arduinoZ], [batteryCLength,batteryCWidth,wallHeight]);
    }
    ridgesCompartment([arduinoX, arduinoY, arduinoZ*2-walle], [arduinoLength, arduinoWidth, wallHeight]);
    ridgesCompartment([mpuX,mpuY,arduinoZ*2-walle], [mpuLength,mpuWidth,wallHeight]);
    ridgesCompartment([batteryCX,batteryCY,arduinoZ*2-walle], [batteryCLength,batteryCWidth,wallHeight]);
}

module clearings() {
    translate([arduinoX-3,-arduinoWidth/2-wall,+wall*7.7]) rotate([90,0,90])
    resize([11,0,0]) cylinder(r=3, h=arduinoLength+5, $fn=res);
    translate([batteryCX-2,batteryCWidth/2,+wall*7.7]) rotate([90,0,90])
    resize([11,0,0]) cylinder(r=3, h=batteryCLength+wall+3, $fn=res);
}

module electronicsHolder() {
    difference() {
        electronics();
        translate([0,0,-4.2]) clearings();
    }
    spacerTowers(height - heightElectronics / 2);
}

module bottom() {
    //rotate([0,180,0]) difference() {
        union() {
            difference() {
                cylinder(r=outerRad, h=heightBottom, $fn=res);
                clearCorners(outerRad);
            }
            roundCorners(outerRad);
        }
    //}
        difference() {
            translate([0,0,0]) cylinder(r=innerRad - looseFit, h=height-heightLEDS-walle, $fn=res);
            translate([0,0,0]) cylinder(r=innerRad - looseFit - wall, h=height - heightLEDS+0.9, $fn=res);
        }
}


module top() {
    difference() {
        union() {
            difference() {
                cylinder(r=outerRad, h=height, $fn=res);
                clearCorners(outerRad);
            }
            roundCorners(outerRad);
        }
        translate([0,0,wall]) cylinder(r=innerRad, h=height, $fn=res);
        //translate([0,0,-wall])holes();
    }
    translate([-batteryLength/2,-batteryWidth/2,0]) batteryCompartment();
}

module charging_wire(radius) {
	rotate_extrude(convexity = 10, $fn=res)
	translate([radius,0,0]) circle(r=charging_wire_radius, $fn=res);
}

top();
translate([0,0,40]) electronicsHolder();
translate([0,0,80]) difference() {
	bottom();
	//translate([0,0,.5]) charging_wire(radius=15);
	//translate([0,0,.5]) charging_wire(radius=20);
	//translate([0,0,.5]) charging_wire(radius=25);
	//translate([0,0,.5]) charging_wire(radius=30);

	//translate([15,0,-5]) cylinder(r=charging_wire_radius, h=10, $fn=res);
	//translate([20,0,-5]) cylinder(r=charging_wire_radius, h=10, $fn=res);
	//translate([25,0,-5]) cylinder(r=charging_wire_radius, h=10, $fn=res);
	//translate([30,0,-5]) cylinder(r=charging_wire_radius, h=10, $fn=res);
}


//charging_wire(count=50, radius=30);

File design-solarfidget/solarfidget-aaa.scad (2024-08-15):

// (ORIGINAL) SOLARFIDGET Copyright (C) 2021, 2022 Kurt Manucredo

// (ORIGINAL) SOLARFIDGET is licensed under a
// CREATIVE COMMONS ATTRIBUTION-NONCOMMERCIAL 4.0 INTERNATIONAL PUBLIC
// LICENSE

// You should have received a copy of the license along with this
// work.  If not, see:
// <https://creativecommons.org/licenses/by-nc/4.0/legalcode>


res=100;
innerRad=35.49;

wall=2;
walle=.8;
wallHeight=2.5;

ridgesRad=.5;

bottomHeight=2;
electronicsHeight=7.2;

arduinoLength=43.55;
arduinoWidth=18.7;

mpuLength=16.2;
mpuWidth=21;

boosterLength=18.7;
boosterWidth=21;

LEDsWidth=12;
LEDsHeight=2;

buttonOffset=4.6;

aaaLength=45.5;
aaar=10.25/2+.3;

module spring_inserts() {

	translate([-.8,aaar,aaar+bottomHeight]) rotate([0,90,0]) cylinder(r=2.5,h=1,$fn=res);
	translate([-2.7,aaar,aaar+bottomHeight]) rotate([0,90,0]) cylinder(r=3.4,h=2,$fn=res);
	translate([-2.7,aaar,aaar+bottomHeight*2]) rotate([0,90,0]) cylinder(r=4,h=1,$fn=res);
	translate([-2.7,aaar-2,aaar+bottomHeight*4]) rotate([0,90,0]) cube([5,1,5]);

	translate([-.8,aaar*5,aaar+bottomHeight]) rotate([0,90,0]) cylinder(r=2.5,h=1,$fn=res);
	translate([-2.7,aaar*5,aaar+bottomHeight]) rotate([0,90,0]) cylinder(r=3.4,h=2,$fn=res);
	translate([-2.7,aaar*5,aaar+bottomHeight*2]) rotate([0,90,0]) cylinder(r=4,h=1,$fn=res);
	translate([-2.7,aaar*5-2,aaar+bottomHeight*4]) rotate([0,90,0]) cube([5,1,5]);

	translate([aaaLength-.1,aaar*3,aaar+bottomHeight]) rotate([0,90,0]) cylinder(r=2.5,h=1,$fn=res);
	translate([aaaLength+.8,aaar*3,aaar+bottomHeight]) rotate([0,90,0]) cylinder(r=3.4,h=2,$fn=res);
	translate([aaaLength+2,aaar*3,aaar+bottomHeight*2]) rotate([0,90,0]) cylinder(r=4,h=1,$fn=res);
	translate([aaaLength+.8-3,aaar*3+1,aaar+bottomHeight*4]) rotate([0,90,0]) cube([5,1,5]);
}

module washer_inserts() {

	translate([-.9,aaar*3,aaar+bottomHeight-1]) rotate([0,90,0]) cylinder(r=4.3,h=1,$fn=res);
	translate([-2.1,aaar*3,aaar+bottomHeight-1]) rotate([0,90,0]) cylinder(r=4.5,h=1.3,$fn=res);

	translate([aaaLength-.1,aaar,aaar+bottomHeight-1]) rotate([0,90,0]) cylinder(r=4.3,h=1,$fn=res);
	translate([aaaLength+.8,aaar,aaar+bottomHeight-1]) rotate([0,90,0]) cylinder(r=4.5,h=1.3,$fn=res);

	translate([aaaLength-.1,aaar*5,aaar+bottomHeight-1]) rotate([0,90,0]) cylinder(r=4.3,h=1,$fn=res);
	translate([aaaLength+.8,aaar*5,aaar+bottomHeight-1]) rotate([0,90,0]) cylinder(r=4.5,h=1.3,$fn=res);
}

module battery_wiring_holes() {

	translate([-27,2.3,4.8]) rotate([0,90,0]) cylinder(r=.75, h=5, $fn=res);
	translate([22.2,-aaar*4+2.5,3.9]) rotate([0,90,0]) cylinder(r=.75, h=5, $fn=res);
	translate([-24.8,-17,7]) rotate([0,90,90]) cylinder(r=.5, h=12, $fn=res);
	translate([25.2,-7,7]) rotate([0,90,90]) cylinder(r=.5, h=12, $fn=res);
}

module battery_side() {

	translate([-walle*2,aaar,aaar]) rotate([0,90,0]) cylinder(r=aaar+1,h=walle*5,$fn=res);
}

module battery_sides() {

	translate([-2.4,0,1]) battery_side();
	translate([-2.4,aaar*2,1]) battery_side();
	translate([-2.4,aaar*4,1]) battery_side();
	translate([aaaLength+1.6,0,1]) battery_side();
	translate([aaaLength+1.6,aaar*2,1]) battery_side();
	translate([aaaLength+1.6,aaar*4,1]) battery_side();
}

module batteries() {

	difference() {
		translate([-22.6,-25.2,0]) _batteries();
		battery_wiring_holes();
	}
}

module _batteries() {

	difference() {
		cube([aaaLength,aaar*6,aaar+bottomHeight]);
		for (i=[0:2:4]) {
			translate([-1,aaar*i+5.5,aaar+bottomHeight]) rotate([0,90,0])
				cylinder(r=aaar,h=aaaLength+2, $fn=res);
		}
		translate([-1,-1,aaar-.5]) cube([aaaLength+2,aaar*6+2.5,aaar+bottomHeight]);
	}
	difference() {
		battery_sides();
		spring_inserts();
		washer_inserts();
		translate([-walle*6,0,11.7]) cube([aaaLength+walle*12,aaar*6,aaar+bottomHeight]);
	}
}

module battery_ori_ind() {

	translate([-17,.5,.8]) minus();
	translate([17,.5,.8]) plus();
	translate([-22,-aaar*2+.5,.8]) plus();
	translate([11,-aaar*2+.5,.8]) minus();
	translate([-17,-aaar*4+.5,.8]) minus();
	translate([17,-aaar*4+.5,.8]) plus();
}

module minus() {

	cube([5,2,3]);
}

module plus() {

	cube([5,2,3]);
	rotate([0,0,90]) translate([-1.5,-3.5,0]) cube([5,2,3]);
}

module compartmentOutside(location,size) {

	translate([location[0]-walle,location[1]-walle,location[2]-walle*2])
		cube([size[0]+walle*2,size[1]+walle*2,size[2]+walle]);
}

module compartmentInside(location,size) {

	translate([location[0],location[1],location[2]-4]) cube([size[0],size[1],size[2]+5]);
}

module ridge(location,size) {

	translate(location) translate([wall,0,-2]) rotate([0,90,0])
		cylinder(r=ridgesRad,h=size[0]-wall*2,$fn=res);
	translate(location) translate([wall,0,-2]) sphere(r=ridgesRad,$fn=res);
	translate(location) translate([wall+size[0]-wall*2,0,-2]) sphere(r=ridgesRad,$fn=res);
}

module ridgesCompartment(location,size) {

	translate([0,0,1]) ridge(location,size);
	translate([0,0,2.85]) ridge(location,size);
	translate([0,size[1],1]) ridge(location,size);
	translate([0,size[1],2.85]) ridge(location,size);
}

module _arduino() {

	difference() {
		translate([-22+walle/2,8,0]) arduino();
		translate([arduinoLength/2-3,17.5,11]) rotate([90,0,90])
			resize([11,0,0]) cylinder(r=3,5,$fn=res);
	}
}

module arduino() {

	Z=10.1;
	difference() {
		compartmentOutside([0,0,bottomHeight],[arduinoLength,arduinoWidth,Z]);
		compartmentInside([0,0,bottomHeight],[arduinoLength,arduinoWidth,Z]);
	}
	ridgesCompartment([0,-.1,bottomHeight+7.8],[arduinoLength,arduinoWidth,Z]);
}

module mpu() {

	Z=4;
	difference() {
		compartmentOutside([0,0,bottomHeight],[mpuWidth,mpuLength,Z]);
		compartmentInside([0,0,bottomHeight],[mpuWidth,mpuLength,Z]);
	}
	ridgesCompartment([0,-.1,bottomHeight+1.5],[mpuWidth,mpuLength,Z]);
}

module booster() {

	Z=4;
	difference() {
		compartmentOutside([0,0,bottomHeight],[boosterWidth-walle,boosterLength,Z]);
		compartmentInside([0,0,bottomHeight],[boosterWidth,boosterLength,Z]);
	}
	ridgesCompartment([0,-.1,bottomHeight+1.5],[boosterWidth,boosterLength,Z]);
}

module electronics() {

	_arduino();
	translate([.9,10.5,0]) mpu();
	translate([-20.8-walle,8,0]) booster();
}

module electronics_wiring_holes() {

	translate([.7,25,6.5]) rotate([0,90,90]) resize([0,6,0]) cylinder(r=1.2,h=3,$fn=res);
	translate([-22.8,11,10]) rotate([0,90,0]) resize([10,0,0])cylinder(r=1,h=10,$fn=res);
	translate([20,11,6.5]) rotate([0,90,0]) cylinder(r=1,h=10,$fn=res);
	translate([-28,0,10]) rotate([0,90,90]) resize([10,0,0]) cylinder(r=1,h=10,$fn=res);
}

module button_holder() {

	translate([-25.75,12.75,bottomHeight])
		cylinder(r=3, h=LEDsWidth-buttonOffset, $fn=res);
	difference() {
		translate([-30.1,8.5,bottomHeight]) cube([8.5,8.5,LEDsWidth-.2]);
		translate([-29.1,9.5,bottomHeight]) cube([6.5,6.5,LEDsWidth+.3]);
	}
}

module bottom() {

	difference() {
		union() {
			fix_towers();
			difference() {
				union() {
					translate([0,0,0]) _bottom();
					electronics();
					batteries();
					button_holder();
				}
				battery_ori_ind();
				electronics_wiring_holes();
			}
		}
		translate([0,0,bottomHeight]) LEDstripe();
	}
	ring_bottom();
}

module _bottom() {

	difference() {
		__bottom();
		translate([0,0,2]) cylinder(r=innerRad+LEDsHeight, h=LEDsWidth+2, $fn=res);
	}
}

module __bottom() {

	cylinder(r=innerRad+LEDsHeight+1.3, h=LEDsWidth+bottomHeight, $fn=res);
	cylinder(r=innerRad+LEDsHeight+4, h=bottomHeight+4, $fn=res);
}

module top() {

	difference() {
		union() {
			cylinder(r=innerRad+LEDsHeight+4,h=bottomHeight,$fn=res);
			translate([0,0,bottomHeight]) cylinder(r=innerRad+LEDsHeight+4,h=LEDsWidth-4,$fn=res);
		}
		translate([0,0,bottomHeight]) cylinder(r=innerRad+LEDsHeight+1.8,h=LEDsWidth+wall,$fn=res);
		translate([0,0,-4]) fix_grooves();
		rotate([0,0,51]) translate([0,0,1]) for (i = [0:1:30]) rotate([0,0,i]) _off_cyl();
	}
	ring_top();
}

module _fix_towers(rad) {

	rotate([0,90,0]) translate([-10,0,-50]) cylinder(r=rad, h=100, $fn=res);
	rotate([90,0,0]) translate([0,10,-50]) cylinder(r=rad, h=100, $fn=res);
}

module fix_towers() {

	difference() {
		_fix_towers(2.3);
		__bottom();
		translate([0,0,6]) difference() {
			cylinder(r=innerRad+LEDsHeight+wall*10, h=LEDsWidth, $fn=res);
			cylinder(r=innerRad+LEDsHeight+2.8, h=LEDsWidth, $fn=res);
		}
	}
}

module fix_grooves() {

	difference() {
		union() {
			for (i = [1:1:5]) {
				translate([0,0,i]) _fix_towers(2.5);
			}
			for (i = [-10:1:10]) {
				translate([0,0,1]) rotate([0,0,i]) _fix_towers(2.5);
			}
			for (i = [0:1:25]) {
				translate([0,0,1-i*.1]) rotate([0,0,i+10]) _fix_towers(2.5);

			}
			for (i = [0:1:25]) {
				translate([0,0,1-i*.1]) rotate([0,0,-i-10]) _fix_towers(2.5);
			}
		}
		__bottom();
		translate([0,0,6]) difference() {
			cylinder(r=innerRad+LEDsHeight+wall*10, h=LEDsWidth-4, $fn=res);
			cylinder(r=innerRad+LEDsHeight+3.2, h=LEDsWidth-4, $fn=res);
		}
	}

}

module LEDstripe() {

	difference() {
		cylinder(r=innerRad+2, h=LEDsWidth, $fn=res);
		translate([0,0,-1]) cylinder(r=innerRad, h=LEDsWidth+2, $fn=res);

	}
}

module ring() {
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

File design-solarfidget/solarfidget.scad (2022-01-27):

// (ORIGINAL) SOLARFIDGET Copyright (C) 2021, 2022 Kurt Manucredo

// (ORIGINAL) SOLARFIDGET is licensed under a
// CREATIVE COMMONS ATTRIBUTION-NONCOMMERCIAL 4.0 INTERNATIONAL PUBLIC
// LICENSE

// You should have received a copy of the license along with this
// work.  If not, see:
// <https://creativecommons.org/licenses/by-nc/4.0/legalcode>


LEDsWidth=12;
LEDsHeight=2;

arduinoLength=43.55;
arduinoWidth=18.7;

mpuLength=16.2;
mpuWidth=21;

batteryCLength=28.5;
batteryCWidth=17.9;

batteryLength=45;
batteryWidth=25;
batteryHeight=8.55+4;

wall=2;
walle = .8;
wallHeight=2.5;

bottomHeight=2;
electronicsHeight=7.2;

innerRad=35.45;

screwShaftRadius=2.4;
screwRadius=1.5;
holeRad=2;
screwOne=[0,23.3,3];
screwTwo=[24,0,3];
screwThree = [0,-23,3];

ridgesRad=.5;

res=100;

module _batteryC() {

	difference() {
		translate([-22+walle/2,8,0]) batteryC();
		translate([batteryCWidth/2-5,17.5,5]) rotate([90,0,90])
			resize([11,0,0]) cylinder(r=3,5,$fn=res);
	}
}

module batteryC() {

	Z=3.5;
	difference() {
		compartmentOutside([0,0,bottomHeight],[batteryCLength,batteryCWidth,Z]);
		compartmentInside([0,0,bottomHeight],[batteryCLength,batteryCWidth,Z]);
	}
	ridgesCompartment([0,-.05,bottomHeight+5],[batteryCLength,batteryCWidth,Z]);
}

module _arduino() {

	difference() {
		translate([-22+walle/2,8,0]) arduino();
		translate([arduinoLength/2-3,17.5,8]) rotate([90,0,90])
			resize([11,0,0]) cylinder(r=3,5,$fn=res);
	}
}

module arduino() {

	Z=6;
	difference() {
		compartmentOutside([0,0,bottomHeight],[arduinoLength,arduinoWidth,Z]);
		compartmentInside([0,0,bottomHeight],[arduinoLength,arduinoWidth,Z]);
	}
	ridgesCompartment([0,-.05,bottomHeight+7],[arduinoLength,arduinoWidth,Z]);
}

module mpu() {

	Z=4;
	difference() {
		compartmentOutside([0,0,bottomHeight],[mpuWidth,mpuLength,Z]);
		compartmentInside([0,0,bottomHeight],[mpuWidth,mpuLength,Z]);
	}
	ridgesCompartment([0,-.05,bottomHeight+5],[mpuWidth,mpuLength,Z]);
}

module magnets () {
	translate([22,24,.45]) cylinder(r=2.47,h=1.6, $fn=res);
	translate([0,34.5,.45]) cylinder(r=2.47,h=1.6, $fn=res);
	translate([0,17,.45]) cylinder(r=2.47,h=1.6, $fn=res);
	translate([-22,24,.45]) cylinder(r=2.47,h=1.6, $fn=res);
}

module LEDstripe() {
	difference() {
		cylinder(r=innerRad+2, h=LEDsWidth, $fn=res);
		translate([0,0,-1]) cylinder(r=innerRad, h=LEDsWidth+2, $fn=res);

	}
}

module batteryCompartment() {
	difference() {
		translate([0,0,0]) rotate([0,0,0]) cube([batteryLength+walle*3, batteryWidth+walle*3, batteryHeight]);
		translate([walle,walle,walle]) rotate([0,0,0]) cube([batteryLength+walle, batteryWidth+walle, batteryHeight]);
		translate([-1,batteryWidth,-1]) cube([5,5,15]);    
		translate([45,batteryWidth,-1]) cube([5,5,15]);    
	}
}

module clearCorners(r) {
	translate([0,0,0]) rotate_extrude(convexity = 10, $fn=res)
	translate([r, 0, 0])
	circle(r=1, $fn=res);
}

module roundCorners(r) {
	translate([0,0,1]) rotate_extrude(convexity = 10, $fn=res)
	translate([r-1, 0, 0])
	circle(r=1, $fn=res);
}

module compartmentOutside(location, size) {
	translate([location[0]-walle, location[1]-walle, location[2]-walle*2])
		cube([size[0]+walle*2, size[1]+walle*2, size[2]+walle]);
}
module compartmentInside(location, size) {
	translate([location[0], location[1], location[2]-4]) cube([size[0], size[1], size[2]+5]);
}

module ridge(location,size) {
	translate(location) translate([wall,0,-2]) rotate([0,90,0]) cylinder(r=ridgesRad,h=size[0]-wall*2, $fn=res);
	translate(location) translate([wall,0,-2]) sphere(r=ridgesRad, $fn=res);
	translate(location) translate([wall+size[0]-wall*2,0,-2]) sphere(r=ridgesRad, $fn=res);
}

module ridgesCompartment(location, size) {
	translate([0,0,-1]) ridge(location, size);
	translate([0,0,-2.85]) ridge(location, size);
	translate([0,size[1],-1]) ridge(location, size);
	translate([0,size[1],-2.85]) ridge(location, size);
}

module clearings() {
	translate([8,-19,-1.5]) cube([batteryCWidth,2,7]);

	translate([-17,17.5,0]) rotate([90,0,90])
	resize([11,0,0]) cylinder(r=3, 5, $fn=res);
}

module charger_top() {
	difference() {
		union() {
			difference() {
				cylinder(r=innerRad+LEDsHeight+wall*1.5, h=bottomHeight, $fn=res);
				clearCorners(innerRad+LEDsHeight+wall*1.5);
	    		}
			roundCorners(innerRad+LEDsHeight+wall*1.5);
			difference() {
				cylinder(r=innerRad+LEDsHeight+wall, h=14, $fn=res);
				translate([0,0,0]) cylinder(r=innerRad+LEDsHeight+wall/2, h=15, $fn=res);
			}
			charging_contact_posts_c();
		}
		charging_contact_posts_c_i();
		magnets();
		translate([0,-35,10])rotate([90,0,0]) resize([5,15,0]) cylinder(r=2, h=10, $fn=res);
	}
}

module charger_bottom() {
	difference() {
		union() {
			difference() {
				cylinder(r=innerRad+LEDsHeight+wall*1.5, h=bottomHeight, $fn=res);
				clearCorners(innerRad+LEDsHeight+wall*1.5);
			}
			roundCorners(innerRad+LEDsHeight+wall*1.5);
			translate([0,0,bottomHeight])
			difference() {
				cylinder(r=innerRad+LEDsHeight+wall*1.5, h=14, $fn=res);
				cylinder(r=innerRad+LEDsHeight+wall, h=15, $fn=res);
			}
		}
		translate([0,-39,7])rotate([90,0,0]) cylinder(r=2, h=2, $fn=res);
	}
}

module bottom() {
	rotate([0,0,0]) difference() {
		union() {
			difference() {
				cylinder(r=innerRad+LEDsHeight+wall*1.5, h=bottomHeight, $fn=res);
				clearCorners(innerRad+LEDsHeight+wall*1.5);
			}
			roundCorners(innerRad+LEDsHeight+wall*1.5);
		}
	}
	difference() {
		translate([0,0,bottomHeight]) cylinder(r=innerRad+LEDsHeight+wall*1.5, h=LEDsWidth, $fn=res);
		translate([0,0,bottomHeight]) cylinder(r=innerRad+LEDsHeight+wall/2 , h=LEDsWidth+wall, $fn=res);
	}
}

module top() {
	difference() {
		union() {
			_top();
			translate([-2,-3.6,0]) union() {
				translate([-4.5,-2.6,0]) _arduino();
				translate([-22,-22,0]) batteryCompartment();
				translate([-5,-21.2,0]) rotate([0,0,90]) mpu();
				translate([-4,-21,0]) batteryC();
			}
		}
		translate([0,0,bottomHeight]) LEDstripe();
	}
}

module _top() {
	difference() {
		union() {
			difference() {
				union() {
					cylinder(r=innerRad+LEDsHeight+wall/2, h=LEDsWidth+bottomHeight, $fn=res);
					difference() {
						cylinder(r=innerRad+LEDsHeight+wall*1.5, h=bottomHeight, $fn=res);
						clearCorners(innerRad+LEDsHeight+wall*1.5);
					}
					roundCorners(innerRad+LEDsHeight+wall*1.5);
				}
				translate([0,0,wall]) cylinder(r=innerRad+LEDsHeight, h=LEDsWidth+wall, $fn=res);
				magnets();
			}
			charging_contact_posts();
		}
		charging_contact_posts_i();
	}
}

module charging_contact_post() {
	cylinder(r=4, h=7.4, $fn=res);
}

module charging_contact_post_i() {
	cylinder(r=2.7, h=3.3, $fn=res);
	cylinder(r=1.5, h=6, $fn=res);
	translate([0,0,-3]) cylinder(r1=9.5, r2=0, h=5, $fn=res);
	translate([0,0,5]) cylinder(r=3.2, h=3, $fn=6);
	translate([0,0,5.75]) rotate([90,0,0]) cylinder(r=0.75, h=4, $fn=res);
	translate([0,0,5.75]) rotate([90,0,-60]) cylinder(r=0.75, h=4, $fn=res);
}

module charging_contact_post_c() {
	cylinder(r=5.5, h=8, $fn=res);
}

module charging_contact_post_c_i() {
	cylinder(r=3, h=6, $fn=res);
	cylinder(r=1.7, h=9, $fn=res);
	translate([0,0,-3]) cylinder(r1=9.5, r2=0, h=5, $fn=res);
}

module charging_contact_posts_c() {
	translate([15,28,0]) charging_contact_post_c();
	translate([5,28,0]) charging_contact_post_c();
	translate([-5,28,0]) charging_contact_post_c();
	translate([-15,28,0]) charging_contact_post_c();
}

module charging_contact_posts_c_i() {
	translate([15,28,0]) charging_contact_post_c_i();
	translate([5,28,0]) charging_contact_post_c_i();
	translate([-5,28,0]) charging_contact_post_c_i();
	translate([-15,28,0]) charging_contact_post_c_i();
}
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

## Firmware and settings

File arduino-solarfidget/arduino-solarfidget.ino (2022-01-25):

/*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
 * You should have received a copy of the GNU Lesser General Public
 * License along with NeoPixel.  If not, see
 * <http://www.gnu.org/licenses/>. */

#include <Adafruit_NeoPixel.h>
// Which pin on the Arduino is connected to the NeoPixels?
#define PIN_NEOPIXEL        6 // On Trinket or Gemma, suggest changing this to 1

// How many NeoPixels are attached to the Arduino?
#define NUMPIXELS_NEOPIXEL 32

// When setting up the NeoPixel library, we tell it how many pixels,
// and which pin to use to send signals. Note that for older NeoPixel
// strips you might need to change the third parameter -- see the
// strandtest example for more information on possible values.
Adafruit_NeoPixel pixels(NUMPIXELS_NEOPIXEL, PIN_NEOPIXEL, NEO_GRB + NEO_KHZ800);

// I2C device class (I2Cdev) demonstration Arduino sketch for MPU6050 class using DMP (MotionApps v2.0)
// 6/21/2012 by Jeff Rowberg <jeff@rowberg.net>
// Updates should (hopefully) always be available at https://github.com/jrowberg/i2cdevlib
//
// Changelog:
//      2019-07-08 - Added Auto Calibration and offset generator
//		   - and altered FIFO retrieval sequence to avoid using blocking code
//      2016-04-18 - Eliminated a potential infinite loop
//      2013-05-08 - added seamless Fastwire support
//                 - added note about gyro calibration
//      2012-06-21 - added note about Arduino 1.0.1 + Leonardo compatibility error
//      2012-06-20 - improved FIFO overflow handling and simplified read process
//      2012-06-19 - completely rearranged DMP initialization code and simplification
//      2012-06-13 - pull gyro and accel data from FIFO packet instead of reading directly
//      2012-06-09 - fix broken FIFO read sequence and change interrupt detection to RISING
//      2012-06-05 - add gravity-compensated initial reference frame acceleration output
//                 - add 3D math helper file to DMP6 example sketch
//                 - add Euler output and Yaw/Pitch/Roll output formats
//      2012-06-04 - remove accel offset clearing for better results (thanks Sungon Lee)
//      2012-06-01 - fixed gyro sensitivity to be 2000 deg/sec instead of 250
//      2012-05-30 - basic DMP initialization working

/* ============================================
I2Cdev device library code is placed under the MIT license
Copyright (c) 2012 Jeff Rowberg

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
THE SOFTWARE IS PROVIDED "AS IS", WITHOUT WARRANTY OF ANY KIND, EXPRESS OR
IMPLIED, INCLUDING BUT NOT LIMITED TO THE WARRANTIES OF MERCHANTABILITY,
FITNESS FOR A PARTICULAR PURPOSE AND NONINFRINGEMENT. IN NO EVENT SHALL THE
AUTHORS OR COPYRIGHT HOLDERS BE LIABLE FOR ANY CLAIM, DAMAGES OR OTHER
LIABILITY, WHETHER IN AN ACTION OF CONTRACT, TORT OR OTHERWISE, ARISING FROM,
OUT OF OR IN CONNECTION WITH THE SOFTWARE OR THE USE OR OTHER DEALINGS IN
THE SOFTWARE.
===============================================
*/

// I2Cdev and MPU6050 must be installed as libraries, or else the .cpp/.h files
// for both classes must be in the include path of your project
#include "I2Cdev.h"

#include "MPU6050_6Axis_MotionApps20.h"
//#include "MPU6050.h" // not necessary if using MotionApps include file

// Arduino Wire library is required if I2Cdev I2CDEV_ARDUINO_WIRE implementation
// is used in I2Cdev.h
#if I2CDEV_IMPLEMENTATION == I2CDEV_ARDUINO_WIRE
    #include "Wire.h"
#endif

// class default I2C address is 0x68
// specific I2C addresses may be passed as a parameter here
// AD0 low = 0x68 (default for SparkFun breakout and InvenSense evaluation board)
// AD0 high = 0x69
MPU6050 mpu;
//MPU6050 mpu(0x69); // <-- use for AD0 high

/* =========================================================================
   NOTE: In addition to connection 3.3v, GND, SDA, and SCL, this sketch
   depends on the MPU-6050's INT pin being connected to the Arduino's
   external interrupt #0 pin. On the Arduino Uno and Mega 2560, this is
   digital I/O pin 2.
 * ========================================================================= */

/* =========================================================================
   NOTE: Arduino v1.0.1 with the Leonardo board generates a compile error
   when using Serial.write(buf, len). The Teapot output uses this method.
   The solution requires a modification to the Arduino USBAPI.h file, which
   is fortunately simple, but annoying. This will be fixed in the next IDE
   release. For more info, see these links:

   http://arduino.cc/forum/index.php/topic,109987.0.html
   http://code.google.com/p/arduino/issues/detail?id=958
 * ========================================================================= */

#define INTERRUPT_PIN 2  // use pin 2 on Arduino Uno & most boards
#define LED_PIN 13 // (Arduino is 13, Teensy is 11, Teensy++ is 6)
bool blinkState = false;

// MPU control/status vars
bool dmpReady = false;  // set true if DMP init was successful
uint8_t mpuIntStatus;   // holds actual interrupt status byte from MPU
uint8_t devStatus;      // return status after each device operation (0 = success, !0 = error)
uint16_t packetSize;    // expected DMP packet size (default is 42 bytes)
uint16_t fifoCount;     // count of all bytes currently in FIFO
uint8_t fifoBuffer[64]; // FIFO storage buffer

// orientation/motion vars
Quaternion q;           // [w, x, y, z]         quaternion container
VectorInt16 aa;         // [x, y, z]            accel sensor measurements
VectorInt16 aaReal;     // [x, y, z]            gravity-free accel sensor measurements
VectorInt16 aaWorld;    // [x, y, z]            world-frame accel sensor measurements
VectorFloat gravity;    // [x, y, z]            gravity vector
float euler[3];         // [psi, theta, phi]    Euler angle container
float ypr[3];           // [yaw, pitch, roll]   yaw/pitch/roll container and gravity vector

// packet structure for InvenSense teapot demo
uint8_t teapotPacket[14] = { '$', 0x02, 0,0, 0,0, 0,0, 0,0, 0x00, 0x00, '\r', '\n' };

// Include SOLARFIDGET code
#define ACCELX		(float)aaReal.x
#define ACCELY		(float)aaReal.y
#define PITCH		ypr[1]
#define ROLL		ypr[2]
#define CHARGING_PIN	8
//#define POWERREPORTING
//#define POWERSAVING
#define AUTO_OFF
#define SERIAL_DEBUG
//#define FIDGET 1

#include <solarfidget.h>

// ================================================================
// ===               INTERRUPT DETECTION ROUTINE                ===
// ================================================================

volatile bool mpuInterrupt = false;     // indicates whether MPU interrupt pin has gone high
void dmpDataReady() {
    mpuInterrupt = true;
}

// ================================================================
// ===                      INITIAL SETUP                       ===
// ================================================================

void setup() {

    // INITIALIZE NeoPixel strip object
    pixels.begin();

    // join I2C bus (I2Cdev library doesn't do this automatically)
    #if I2CDEV_IMPLEMENTATION == I2CDEV_ARDUINO_WIRE
        Wire.begin();
        Wire.setClock(400000); // 400kHz I2C clock. Comment this line if having compilation difficulties
    #elif I2CDEV_IMPLEMENTATION == I2CDEV_BUILTIN_FASTWIRE
        Fastwire::setup(400, true);
    #endif

    #ifdef SERIAL_DEBUG
    // initialize serial communication
    // (115200 chosen because it is required for Teapot Demo output, but it's
    // really up to you depending on your project)
    Serial.begin(115200);
    while (!Serial); // wait for Leonardo enumeration, others continue immediately

    // NOTE: 8MHz or slower host processors, like the Teensy @ 3.3V or Arduino
    // Pro Mini running at 3.3V, cannot handle this baud rate reliably due to
    // the baud timing being too misaligned with processor ticks. You must use
    // 38400 or slower in these cases, or use some kind of external separate
    // crystal solution for the UART timer.

    // initialize device
    Serial.println(F("Initializing I2C devices..."));
    #endif

    mpu.initialize();
    pinMode(INTERRUPT_PIN, INPUT);

    #ifdef SERIAL_DEBUG
    // verify connection
    Serial.println(F("Testing device connections..."));
    Serial.println(mpu.testConnection() ? F("MPU6050 connection successful") : F("MPU6050 connection failed"));
    #endif

    // load and configure the DMP
    #ifdef SERIAL_DEBUG
    Serial.println(F("Initializing DMP..."));
    #endif
    devStatus = mpu.dmpInitialize();

#if (FIDGET == 1)
    // Fill in your calibration values here
    mpu.setXAccelOffset(0);
    mpu.setYAccelOffset(0);
    mpu.setZAccelOffset(0);
    mpu.setXGyroOffset(0);
    mpu.setYGyroOffset(0);
    mpu.setZGyroOffset(0);
#endif

    // make sure it worked (returns 0 if so)
    if (devStatus == 0) {
        // Calibration Time: generate offsets and calibrate our MPU6050
        #ifdef SERIAL_DEBUG
        mpu.CalibrateAccel(20);
	Serial.println("");
        mpu.CalibrateGyro(20);
        mpu.PrintActiveOffsets();

        // turn on the DMP, now that it's ready
        Serial.println(F("Enabling DMP..."));
        #endif
        mpu.setDMPEnabled(true);

        #ifdef SERIAL_DEBUG
        // enable Arduino interrupt detection
        Serial.print(F("Enabling interrupt detection (Arduino external interrupt "));
        Serial.print(digitalPinToInterrupt(INTERRUPT_PIN));
        Serial.println(F(")..."));
        #endif

        attachInterrupt(digitalPinToInterrupt(INTERRUPT_PIN), dmpDataReady, RISING);
        mpuIntStatus = mpu.getIntStatus();

        // set our DMP Ready flag so the main loop() function knows it's okay to use it
        #ifdef SERIAL_DEBUG
        Serial.println(F("DMP ready! Waiting for first interrupt..."));
        #endif
        dmpReady = true;

        // get expected DMP packet size for later comparison
        packetSize = mpu.dmpGetFIFOPacketSize();
    } else {
        // ERROR!
        // 1 = initial memory load failed
        // 2 = DMP configuration updates failed
        // (if it's going to break, usually the code will be 1)
        #ifdef SERIAL_DEBUG
        Serial.print(F("DMP Initialization failed (code "));
        Serial.print(devStatus);
        Serial.println(F(")"));
        #endif
    }

    // configure LED for output
    pinMode(LED_PIN, OUTPUT);

    #ifdef POWERREPORTING
    // configure charging pin
    pinMode(CHARGING_PIN, INPUT);
    #endif
}



// ================================================================
// ===                    MAIN PROGRAM LOOP                     ===
// ================================================================

void loop() {
    // if programming failed, don't try to do anything
    if (!dmpReady) return;
    // read a packet from FIFO
    if (mpu.dmpGetCurrentFIFOPacket(fifoBuffer)) { // Get the Latest packet 
        mpu.dmpGetQuaternion(&q, fifoBuffer);
        mpu.dmpGetAccel(&aa, fifoBuffer);
        mpu.dmpGetGravity(&gravity, &q);
	mpu.dmpGetYawPitchRoll(ypr, &q, &gravity);
        mpu.dmpGetLinearAccel(&aaReal, &aa, &gravity);
	solarfidget();
        // blink LED to indicate activity
        blinkState = !blinkState;
        digitalWrite(LED_PIN, blinkState);
    }
}

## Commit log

2021-09-17 use auto calibration
2021-10-10 fix gravity and acceleration calculations
    [arduino-solarfidget.ino]
2021-10-12 add design files
    [charger-bottom.3mf, charger-top.3mf, solarfidget-bottom.3mf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]
2021-10-13 show calibration values
2021-10-14 fix charging tower nut size
    [solarfidget-top.3mf, solarfidget.scad]
2021-12-01 fix last LED: is the same as LED 0
2021-12-01 fix last LED: remove on "if"
2021-12-09 add powersaving
2021-12-09 add power reporting
2021-12-09 power reporting fixes
2022-01-09 inital design upload for 3xaaa battery version
    [solarfidget-aaa.scad]
2022-01-10 fix battery wiring holes
    [solarfidget-aaa.scad]
2022-01-10 have both top and bottom parts active
    [solarfidget-aaa.scad]
2022-01-25 reduce to 32 LEDs
2022-01-25 replace with new version of design
    [solarfidget.scad]
2022-01-25 update license
    [solarfidget-aaa.scad, solarfidget.scad]
2022-01-25 update 3mf files
    [charger-bottom.3mf, charger-top.3mf, solarfidget-aaa-bottom.3mf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]
2022-01-25 update magnet instructions
2022-01-25 update usb cable instructions
2022-01-25 update LED strip instructions
2022-01-25 update soldering instructions
2022-01-25 update soldering instructions for the battery charging breakout board
2022-01-25 update soldering instructions for the MPU6050
2022-01-25 update soldering instructions for MOLEX plug
2022-01-25 update soldering instructions for LED strip
2022-01-25 update battery instructions
2022-01-25 update charging station instructions
2022-01-25 update battery charging breakout board instructions
2022-01-26 add printing instructions
2022-01-26 update solarfidget design
    [solarfidget.scad]
2022-01-26 update copyright notices
    [solarfidget-aaa.scad, solarfidget.scad]
2022-01-26 update openscad design
    [solarfidget-aaa.scad]
2022-02-14 add development platform design file
    [solarfidget-24leds.scad]
2022-05-29 increase influence of gravity/fix calc. for Pluto
    When the numbers get very small, which is the case when calculating the
    numbers for Pluto, odd things can happen. For instance, the light might
    end up 180 degrees set off from where it should be. Now, this doesn't
    happen with every build I make. Since the only differences from one
    build to another are the accelerator and gyroscope offsets, I assume,
    that this might play a role in it. As far as I can tell, when the
    gyroscope offsets are above the usual offsets, the odd things start
    happening. To mitigate this we increasing the influence of gravity. I
    strongly assume that cheap MPU6050 breakout boards have a too high
    offset and therefore cause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
2023-03-08 new constant
    [solarfidget-aaa.scad]
2023-03-08 change shape of sides
    [solarfidget-aaa.scad]
2023-03-08 change on/off mechanism 1/2
    [solarfidget-aaa.scad]
2023-03-08 change on/off mechanism 2/2
    [solarfidget-aaa.scad]
2023-03-08 reverse historic top/bottom
    [solarfidget-aaa.scad]
2023-03-08 final fix and cleanup
    [solarfidget-aaa.scad]
2023-03-08 use 'res' const
    [solarfidget-aaa.scad]
2023-07-17 Reduce diameter of fidget and light scattering
    [solarfidget-aaa.scad]
2023-07-17 update 3mf files for aaa variant
    [solarfidget-aaa-bottom.3mf, solarfidget-aaa-top.3mf]
2024-02-26 loosen on/off mechanism
    New 3d printers with input shaping exhibit slightly different print
    dimensions. This can lead to very tight tolerances around the on/off
    mechanism. The design is already made so that the mechanism still works
    even if the mechanism is loose. Therefore loosen the mechanism so much
    so that if printed on a prusa mk4 with input shaping the mechanism
    doesn't lock in place. After printing the loosened version on mk4, I no
    longer had to post process the parts, which is a nice side effect of
    this change.
    [solarfidget-aaa.scad]
2024-02-27 adjust height of button holder
    [solarfidget-aaa.scad]
2024-02-27 update 3mf
    [solarfidget-aaa-bottom.3mf]
2024-08-15 make it easier to insert spring
    [solarfidget-aaa.scad]
2024-08-15 update 3mf file for solarfidget aaa bottom
    [solarfidget-aaa-bottom.3mf]

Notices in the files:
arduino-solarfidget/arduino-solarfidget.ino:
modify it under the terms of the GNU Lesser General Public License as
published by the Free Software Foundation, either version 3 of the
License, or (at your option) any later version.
